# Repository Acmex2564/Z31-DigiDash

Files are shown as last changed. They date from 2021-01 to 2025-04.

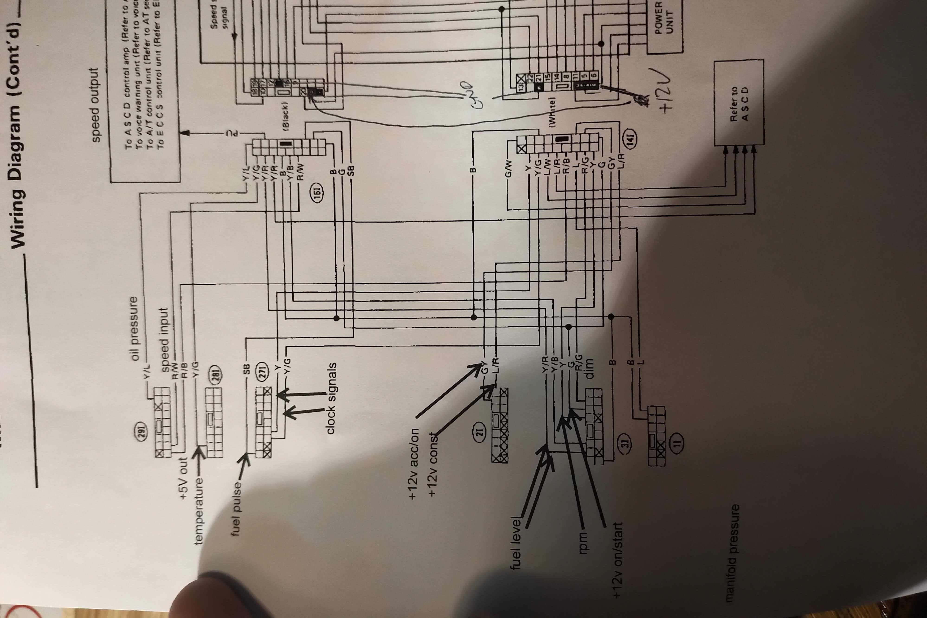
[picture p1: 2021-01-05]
Images/ex_IMG_20210104_2119277.jpg

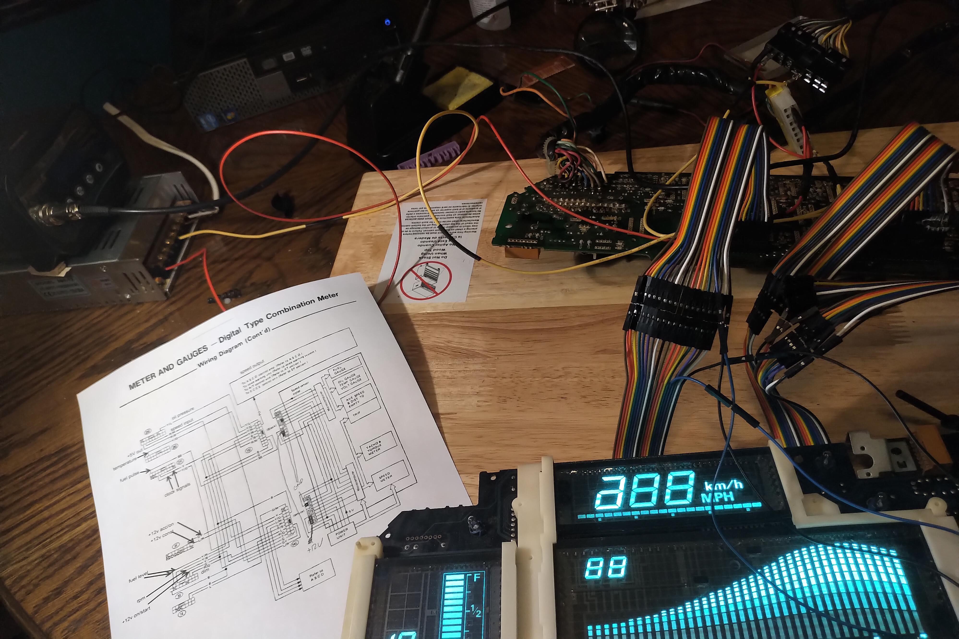
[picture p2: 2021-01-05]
Images/ex_IMG_20210104_2118492.jpg

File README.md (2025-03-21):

# Z31-DigiDash
Reverse Engineering of the 300zx (Z31) Digital Cluster &amp; Design of replacement PCBs

Z31 digital clusters are one of, if not the best examples of this pure 1980s trend. Comprehensive instrumentation, large graphics, and gorgeous VFD illumination were a somewhat expensive option on the 300zx, as well as on Maxima, 240SX, Corvette, Celica/Supra, and a variety of other cars. As the cars languished in the transition period between "late model" and "classic", though, the digital package for the 300zx was not well liked.

It had 3 major issues:

* Terrible update speed
* Lack of brightness
* Unreliability

Now, as Z31s sit at the bottom of the depreciation curve, more people see them as '80s Grand Touring icons and not just as transporation or "sports cars", and a functioning digital dash can be a highlight instead of a detractor.

I have the personal goal of solving at least two of the 3 main problems with these units, by reverse engineering them in the existing state, and designing a drop-on processor board and replacement power supply module. 

See files "Physical Description.md", "Logical Description.md", and "Electrical Description.md" for my observations so far. Also present are images showing how to power up the dash out of the car, and a picture of a printout that I used to map out the input pins.

Note: I am a hobbiest. I am not a EE, CS, Developer, or any related field. Generally, I do my best to read and cargo-cult my way into a working solution. Progress will be slow. The modular design has made it easy to get quick progress and seize control of the actual display, so input, input protection, and power supply will be the main challenges.

Note: None of the boards as-presented are in a state fit to be used without major effort. Big chunks of the Compute-Early-1 design were never tested before I moved on to Compute-Early-2 after component obselecence, etc. and the code to do more than flash the display on the bench was never developed.

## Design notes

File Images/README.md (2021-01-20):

# Powerup & Analysis Images

These images show the contacts on the stock connectors used to power up the cluster out of the car. Forgive the mess and the nano living off to the side, I had to set the project aside for a few months right after working out how to seize control of the VFD shift registers and light arbitrary segments of the displays. Having just returned to it, this is the same configuration it was in after completing that step. 

# FOR THE LOVE OF GOD, DON'T USE MY WIRE COLORS
I suspect I may have been slightly inebriated when creating this test harness, but it does work.

YELLOW IS GROUND (A total of 3, don't skimp!)
RED IS +12V (A total of 4, through two are common on the PCB anyway)

THIS WAS DUMB. DON'T DO IT. If you have connector housings for the male pins available, use those instead of bare pins. Don't just stuff bare wire in the sockets; it's mechanically and electrically poor. At least use alligator clips; it sucks but works slightly better. 

Also here are screencaps of the filament drive waveforms. Sadly, the trip meter driver has been intermittent since I got the cluster, and it was not alive while I was capturing these images.

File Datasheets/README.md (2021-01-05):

# Datasheets 

These all remain property of NEC, Hitachi, or whomever owns them now. I downloaded them off the internet, I doubt they care much anymore. 

NEC uPD6300C is the interesting one -- 20-bit serial shift-register and FIP driver.

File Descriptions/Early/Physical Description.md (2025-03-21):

# Physical Description (Early Clusters, 1984-1896)
The cluster is designed in a highly modular fashion which will dramatically ease the process. Most of the Vacuum Fluorescent Displays (VFDs) are located on a single PCB, along with their driver ICs. The trip meter display and driver is located on an additional sub-module. The mechanical odometer is an additional sub-module. The processor board is similar in footprint to the main display board, and is connected to the display board by two, twenty-by-one JAE terminal strips, and is mechanically fastened by 4 fasteners in the middle of the boards and several more along the perimeter. The processor board connects to the car by two Sumitomo 58S-series wire-to-wire connectors, totalling 32 contacts (31 used). The processor board also connects to a power supply module via two AMP(?) wire-to-board connectors, totalling 28 contacts (though not all are used).

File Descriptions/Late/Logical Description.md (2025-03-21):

# Logical description of a 1987 Model Year 300zx Digital Gauge Cluster

# Processor Board

# Display Board

# Power Supply Module

# Information Display

# Check display

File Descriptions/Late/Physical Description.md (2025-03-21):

# Physical Description (Late Clusters, 1987-1989)
The cluster is designed in a highly modular fashion which will dramatically ease the process of reverse engineering. Most of the Vacuum Fluorescent Displays (VFDs) are located on a single PCB, along with their driver ICs. The information display and driver is located on an additional sub-module. The mechanical odometer is an additional sub-module, as is the edge-lit "diagnostic display". The processor board is similar in footprint to the main display board, and is connected to the display board by two, twenty-by-one JAE terminal strips, and is mechanically fastened by 4 fasteners in the middle of the boards and several more along the perimeter. The processor board connects to the car by two Sumitomo 58S-series wire-to-wire connectors, totalling 32 contacts (31 used). The processor board also connects to a power supply module via one AMP(?) wire-to-board connectors, totalling 16 contacts (though not all are used).

The major differences between the Early and Late clusters are as follows:
* Late clusters use colored segments in the fuel gauge, tachometer, and temperature VFDs
* Late clusters use a "check" display for some vehicle parameters
* Late clusters use a simpler power supply in the same case, with a user-replacable fuse (instead of through-hole polyfuses or trace fuses)
* Late clusters have significantly more silkscreening, most of it in English, which will aid reverse engineering

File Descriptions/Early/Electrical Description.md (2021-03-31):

# Electrical Description of a 1984 Model 300zx Digital Gauge Cluster

# Main Harness Connectors
There are 3 connectors, Sumitomo 58S-type, colored/keyed white/black/blue. Blue is the warning light pcb, and not of concern. White/black are the cluster connectors.
These are 16 position connectors, with 31 of 32 positions occupied. The numbering scheme is eccentric. 

|Pin # | Description | Connector
|---:| --- | :---
| 1.| +12V Constant | White
| 2. (&2')| GND | Black (White)
| 3. (&3')| +12V On/Start | White (Black)
| 4.| +12V Acc/On | White
| 5.| Illumination (Dim) | White
| 6.| Coil Negative (Tach) | White
| 7.| Illumination 2 | White
| 8.| +5V Out | White
| 9.| Speed Sensor In | Black
|10.| Speed Sensor Out | Black
|12.| ASCD On| Black
|13.| ASCD Cruise| White
|14.| ASCD Set Disp 1| White
|15.| ASCD Set Disp 2| White
|16.| Fuel Level (Main) | Black
|17.| Fuel Level (Sub) | Black
|18.| Oil Pressure | Black
|19.| Water Temperature | Black
|20.| Fuel Injection Pulse | Black
|21.| Time Clock 1| White
|22.| Time Clock 2| White
|23.| N/C | White
|24.| O2 Sensor ("30K MI SW") |White
|25 | Charge Warning | Black
|26.| Fuel Warning | Black
|27.| Oil Pressure Warning | Black
|28.| Security Lamp Low Side Switch | Black
|29.| +12V Security | Black
|30.| Ground (AGND?) |Black

# Signal Acquisition
There are four analog (resistance) signals acquired directly by the processor board:
* Fuel Level (Main)
* Fuel Level (Sub)
* Water Temperature
* Oil Pressure

Each of these is configured as a voltage divider with a 5V supply, a resistance between the supply and the ADC, "R(1)", and the resistive sensor between the ADC and ground "R(2)".

On the processor board, the values for R1 are given below:

|Pin #|Wire Color|Description|Designator|Value
|---:|---|---|:---|:---
|16. |Y/B|Fuel Level (Main)|R80|82Ω
|17. |Y/R|Fuel Level (Sub)|R81|100Ω
|18. |Y/L|Oil Pressure|R79|43Ω 2% (G)
|19. |Y/G|Water Temp|R78|43Ω 2G (G)

These produce the following ADC voltages, based on the values specified in the service manual, for the digital tank gauge sending unit:
|Pin #|Description|Range (Ω)|Range (V)
|---: |---|:---|:---
|16.  |Fuel Level (Main)|10Ω(@F) <-> 520Ω(@E)|0.54V(@F) <-> 4.3V(@E)
|17.  |Fuel Leve (Sub)  |0Ω <-> 930Ω|0.2V(@0.25) <-> 4.5V(@E)
|18.  |Oil Pressure |
|19.  |Water Temp |

Although the precise nature of the signal acquisition cannot be determined due to the presence of ceramic "hybrid" integrated circuits, these values are reasonable for the 5V ADCs present on the board. 
Sufficient headroom remains that values out of range will allow the MCU to detect short/open circuit conditions, and disregard any such readings.

# Display Board
|Pin # | Description | AC Volts | AC Freq. | DC Volts (Offset)
|-----:|--- |:--- |:--- |:---
|3. | ? | 0 | N/A | +5V
|9. | ? | 0 | N/A | +5V
|13. | Volt/Pres/Temp Filament A | 2.6V | 103kHz | -18.5V
|14. | Volt/Pres/Temp Filament B | 2.6V | 103kHz | -18.5V
|15. | Tachometer Filament A | 3.2V | 103kHz | -18.5V
|16. | Tachometer Filament B | 3.2V | 103kHz | -18.5V
|17. | Speedometer Filament A | 3.4V | 103kHz | -18.5V
|18. | Speedometer Filament B | 3.4V | 103kHz | -18.5V
|19. | Fuel Filament A | 2.3V | 152kHz | -18.5V
|20. | Fuel Filament B | 2.3V | 152kHz | -18.5V
|21. | Vss (GND) | 0 | N/A | 0V
|22. | Vss (GND) | 0 | N/A | 0V
|23. | Grid/Anode Bias | 0 | N/A | -22.5
|24. | N/C | N/A | N/A | N/A
|25. | Vcc (Logic Supply) | 0 | N/A | +5V
|26. | Vcc (Logic Supply) | 0 | N/A | +5V
|27. | N/C | N/A | N/A | N/A
|28. | N/C | N/A | N/A | N/A
|37. | Tachometer Filament Dupe
|38. | Tachometer Filament Dupe
|39. | Trip Computer Filament Dupe
|40. | Trip Computer Filament Dupe

# Trip Meter Module
|Pin # | Description | AC Volts | AC Freq. | DC Volts (Offset)
|-----:|--- |:--- |:--- |:---
|5. | Trip Computer Filament A | | | -18.5V
|6. | Trip Computer Filament B | | | -18.5V
|19. | Vcc (Logic Supply)  | ? | ??? | +5V
|21. | Grid/Anode Bias | 0 | N/A | -22.5
|22. | Vss (GND) | 0 | N/A | 0V

Resistance values for the filaments are necessary to determine the nominal drive current. They measure at:

|Pin # | Description | Pair Resistance | Anticipated Current
|-----:|--- |:--- |:---
|13. | Volt/Pres/Temp Filament A | 2.8Ω | 930mA 
|14. | Volt/Pres/Temp Filament B | 2.6Ω | 930mA 
|15. | Tachometer Filament A | 2.0Ω | 1600mA 
|16. | Tachometer Filament B | 2.0Ω | 1600mA 
|17. | Speedometer Filament A | 6.1Ω | 560mA 
|18. | Speedometer Filament B | 6.1Ω | 560mA 
|19. | Fuel Filament A | 2.6Ω | 880mA 
|20. | Fuel Filament B | 2.6Ω | 880mA 

However, this is incorrect. Despite reading about the PTC nature of the filaments, I didn't actually comprehend this. 
I measured approximately 40mA AC filament current at 2.4V RMS for the Volt/Pres/Temp VFD panel, in addition to 7mA of DC grid/anode current with all segments illuminated. 

|Pin # | Description | Pair Resistance | Anticipated Current
|-----:|--- |:--- |:---
|5. | Trip Computer Filament A | | 
|6. | Trip Computer Filament B | | 

These currents are very high, which explains the high operating temperature of the stock power supply box.

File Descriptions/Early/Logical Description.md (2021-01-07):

# Logical description of a 1984 Model Year 300zx Digital Gauge Cluster

In keeping with the modular physical construction of the gauge cluster, the signal architecture is also laid out in a sensible manner.

# Processor Board

Due to the limited processing capability of 1970s microcontrollers, the cluster is organized around:

* Two Hitachi HD6301VP microcontrollers (MCUs)
* A Hitachi HD46821P (AKA HD6821P) Peripheral Interface Adapter (PIA)
* A Hitachi HM6117LPJ-3 CMOS Static RAM (SRAM).
* Toshiba TC5090AP Phentaphasic Integration Analog-to-Digital Converter(s)

* Other assorted Transistor-Transistor Logic (TTL) chips

As laid out in the FSM, the cluster can be thought of as basically two separate computers:

* One responsible for the Fuel, Temperature, Voltage, and Oil Pressure
* One responsible for speed, tachometer, and manifold pressure. 

Some additional discrete components are responsible for deriving the negative voltages that are sent to the power supply module.

# Display Board

The only significant ICs on this board are 11  NEC uPD6300C 20-bit combination shift-register and Fluorescent Indicator Panel (FIP) drivers. 
These take a serial stream from a microprocessor, shifting the input from serial to parallel outputs to the anodes and grids of the actual VFD modules. 

These are split into two serial banks, one for each processor. All the chips in a bank share the Serial Clock (SCK), Serial In (SI), and Latch (LH) inputs. 
Nearly each of these drivers operates in a standalone mode, with it's own Chip Select (CS) pin to the appropriate MCU. 
The exception are the two drivers for the Tachometer; the Serial Out of the first driver is connected to the Serial In of the second. 
All drivers share the Blanking Input (BI) pin, which is the global display enable/disable. 

From this point forward, I will refer to these as the "Main" drivers, for the speed and tachometer displays, and the "Satellite" drivers for the other displays. Due to the lack of convenient reference designators for these ICs, I will use the designator for the closest Resistor Array (RA) to identify them. 

All pins for these drivers are brought out to the two connectors between the processor and display board, lableled "CONN 1" and "CONN 2", with a continuous numbering from 1-40 on the board. Power signals are omitted here.

|Pin # | Description | Gauge Panel
|-----:|--- |:---
|1. | ~BI | All
|2. | ~SCK (Satellite) | Fuel, Temp, Volts, Oil Pressure
|4. | ~CS (Driver RA14)  | Fuel (Quantity)
|5. | ~CS (Driver RA16)  | Oil
|6. | ~CS (Driver RA17)  | Water Temperature
|7. | ~CS (Driver RA19)  | Volts
|8. | ~CS (Driver RA15)  | Fuel (Level)
|10. | LH (Satellite) | Fuel, Temp, Volts, Oil Pressure
|11. | SI (Satellite) | Fuel, Temp, Volts, Oil Pressure
|29. | SI (Main)
|30. | LH (Main)
|31. | ~CS (Driver RA7)
|32. | ~CS (Driver RA12)
|33. | ~CS (Driver RA10)
|34. | ~CS (Driver RA4)
|35. | ~CS (Driver RA5)
|36. | ~SCK (Main)

# Power Supply Module

The power supply module produces the pulsed DC filament drive required to evenly light VFDs. It also produces 5VDC for the engine bay sensors, though NOT the 5VDC for the processor(s) or SRAM retention. 
There are no large ICs on this board; only power transistors, diodes, coupling transformers, and passive components. 
As I do not intend to reuse this module, I have focused effort here on understanding it's inputs and outputs. 
This will be (or has been) documented in the "Electrical Description"

# Trip Meter Module

Same story here -- two Mitsubishi M54844P 8-Digit, 8-Segment FIP Drivers. These read in parallel hex data convert it to 8 digits of 7 segment output. 
Two connectors, no visible numbering though. They did provide reference designators for the chips though, which is nice. 

CONN 1
|Pin # | Description
|-----:|---
|1. | S0 (IC31)
|2. | S1 (IC31)
|3. | S2 (IC31)
|4. | S3 (IC31)
|7. | S0 (IC30)
|8. | S1 (IC30)
|9. | S2 (IC30)
|10. | S3 (IC30)

CONN 2
|Pin # | Description
|-----:|---
|11. | RESET (IC30)
|12. | ~WR (IC30)
|15. | ~WR (IC31)
|16. | CTL (IC31)
|18. | RESET (IC31)
|20. | MODE (IC30)

I think these may be tied in with a 3-to-8 line converter and a timebase generator on the processor board, but have not yet sounded this out. The reasoning is that the clock (A 555 timer) is on the module, with no possible sync to the MCU. The external clock is required because the M54844P does output multiplexing, but how are the inputs synchronized? It only has to do 8 inputs, because the drivers are placed reset to change the displayed output, but surely some form of sync is needed?

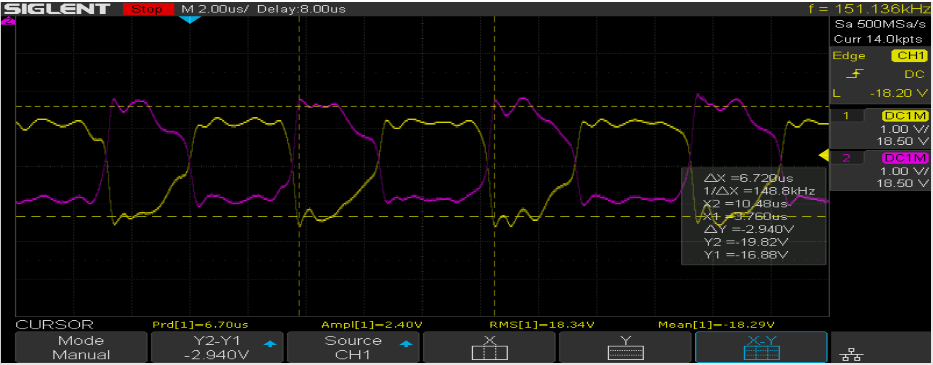
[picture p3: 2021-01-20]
Images/Waveform_FD_Fuel_2.PNG

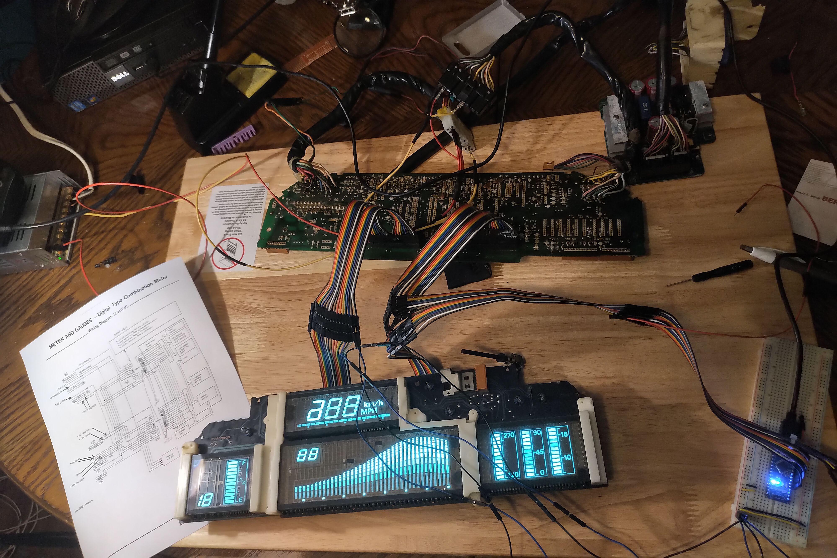
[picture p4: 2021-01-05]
Images/ex_IMG_20210104_2118250.jpg

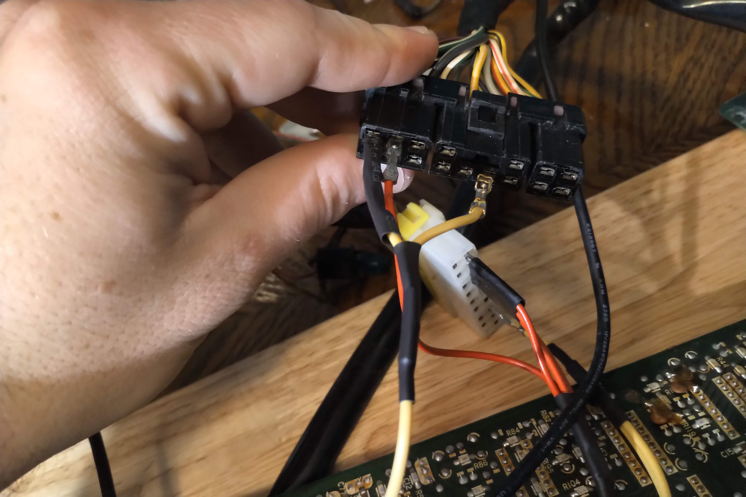
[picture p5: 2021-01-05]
Images/ex_IMG_20210104_2118332.jpg

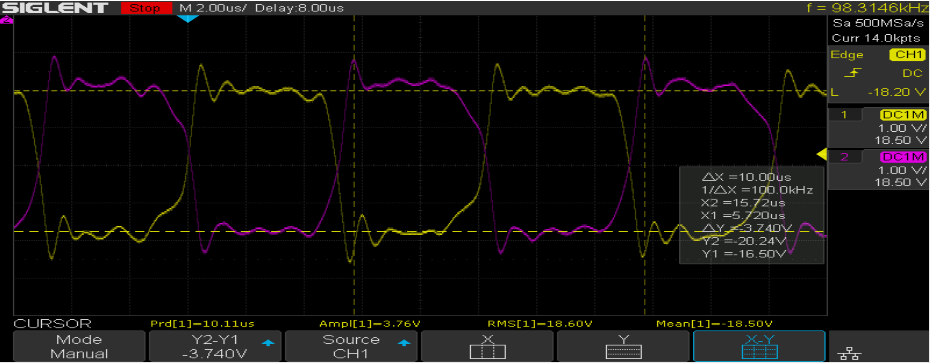
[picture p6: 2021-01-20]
Images/Waveform_FD_Speed.PNG

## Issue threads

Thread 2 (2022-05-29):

Put 5V regulator on cluster compute module

Acmex2564, 2022-05-29:
Debugging is inconvenient when 5V is generated off-board. Put the linear regulator replacement somewhere on the compute module

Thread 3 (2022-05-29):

Correct board connector location

Acmex2564, 2022-05-29:
Current connector locations are not conducive to getting the cables out of the cluster housing. Relocate them to approximate existing connector locations.

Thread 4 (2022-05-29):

Correct cluster housing back stays

Acmex2564, 2022-05-29:
Stock cluster compute modules use a pair of standoffs to the back of the cluster housing. These should be retained.

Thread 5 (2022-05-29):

Incorrect voltage dividers on analog voltage inputs to MCP3008.

Acmex2564, 2022-05-29:
Voltage dividers are reversed.

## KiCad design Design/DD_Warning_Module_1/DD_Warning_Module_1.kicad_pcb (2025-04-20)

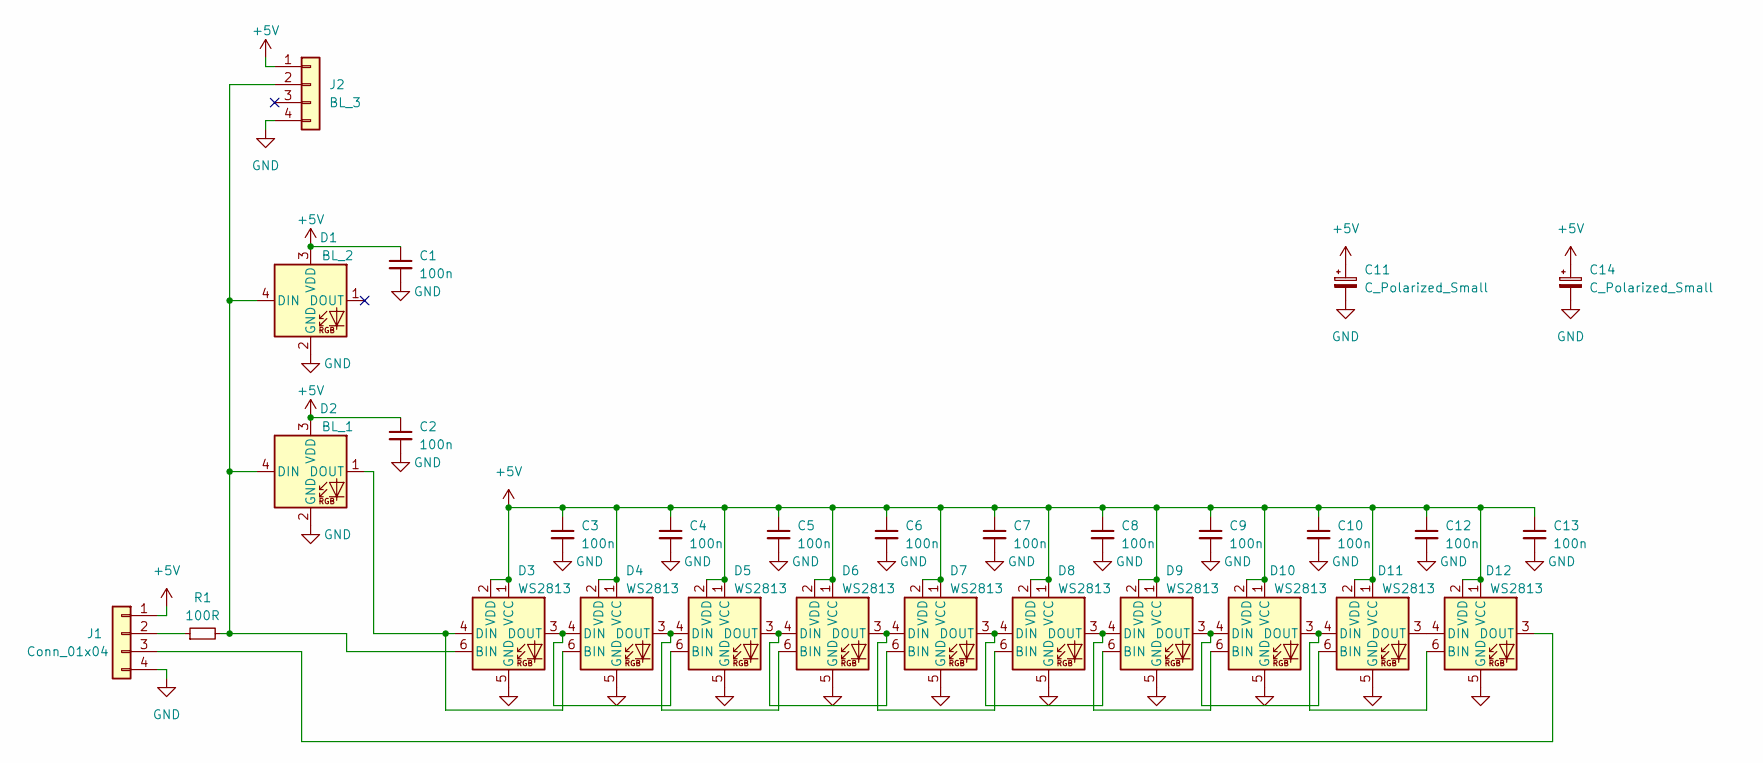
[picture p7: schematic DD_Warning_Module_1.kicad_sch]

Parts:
C1, C2, C3, C4, C5, C6, C7, C8, C9, C10, C12, C13: 100n; C_0805_2012Metric_Pad1.18x1.45mm_HandSolder
C11, C14: C_Polarized_Small; CP_Radial_D8.0mm_P2.50mm
D1: BL_2; LED_D5.0mm-4_RGB
D2: BL_1; LED_D5.0mm-4_RGB
D3, D4, D5, D6, D7, D8, D9, D10, D11, D12: WS2813; LED_WS2812_PLCC6_5.0x5.0mm_P1.6mm
J1: Conn_01x04; JST_XH_B4B-XH-A_1x04_P2.50mm_Vertical
J2: BL_3; JST_XH_B4B-XH-A_1x04_P2.50mm_Vertical
R1: 100R; R_0805_2012Metric_Pad1.20x1.40mm_HandSolder

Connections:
+5V: C1.1, C2.1, C3.1, C4.1, C5.1, C6.1, C7.1, C8.1, C9.1, C10.1, C11.1, C12.1, C13.1, C14.1, D1.3 (VDD), D2.3 (VDD), D3.1 (VCC), D3.2 (VDD), D4.1 (VCC), D4.2 (VDD), D5.1 (VCC), D5.2 (VDD), D6.1 (VCC), D6.2 (VDD), D7.1 (VCC), D7.2 (VDD), D8.1 (VCC), D8.2 (VDD), D9.1 (VCC), D9.2 (VDD), D10.1 (VCC), D10.2 (VDD), D11.1 (VCC), D11.2 (VDD), D12.1 (VCC), D12.2 (VDD), J1.1, J2.1
GND: C1.2, C2.2, C3.2, C4.2, C5.2, C6.2, C7.2, C8.2, C9.2, C10.2, C11.2, C12.2, C13.2, C14.2, D1.2 (GND), D2.2 (GND), D3.5 (GND), D4.5 (GND), D5.5 (GND), D6.5 (GND), D7.5 (GND), D8.5 (GND), D9.5 (GND), D10.5 (GND), D11.5 (GND), D12.5 (GND), J1.4, J2.4
unnamed: D1.4 (DIN), D2.4 (DIN), D3.6 (BIN), J2.2, R1.2
unnamed: D2.1 (DOUT), D3.4 (DIN), D4.6 (BIN)
unnamed: D3.3 (DOUT), D4.4 (DIN), D5.6 (BIN)
unnamed: D4.3 (DOUT), D5.4 (DIN), D6.6 (BIN)
unnamed: D5.3 (DOUT), D6.4 (DIN), D7.6 (BIN)
unnamed: D6.3 (DOUT), D7.4 (DIN), D8.6 (BIN)
unnamed: D7.3 (DOUT), D8.4 (DIN), D9.6 (BIN)
unnamed: D8.3 (DOUT), D9.4 (DIN), D10.6 (BIN)
unnamed: D9.3 (DOUT), D10.4 (DIN), D11.6 (BIN)
unnamed: D10.3 (DOUT), D11.4 (DIN), D12.6 (BIN)
unnamed: D11.3 (DOUT), D12.4 (DIN)
unnamed: D12.3 (DOUT), J1.3
unnamed: J1.2, R1.1

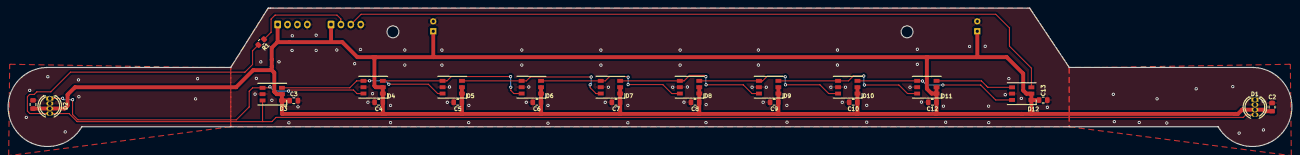
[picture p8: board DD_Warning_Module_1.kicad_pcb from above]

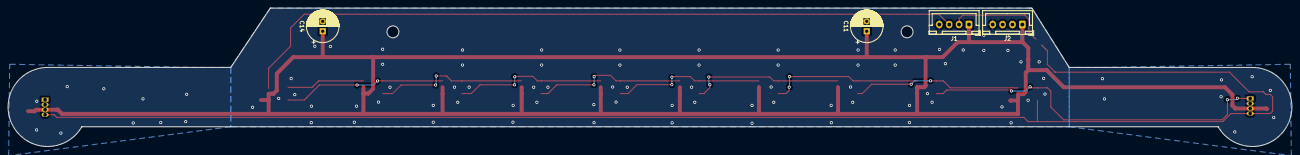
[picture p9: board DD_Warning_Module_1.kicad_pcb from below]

Board: 2 copper layers, 324.6 x 35.0 mm, 29 parts (4 on the bottom side), 15 nets.

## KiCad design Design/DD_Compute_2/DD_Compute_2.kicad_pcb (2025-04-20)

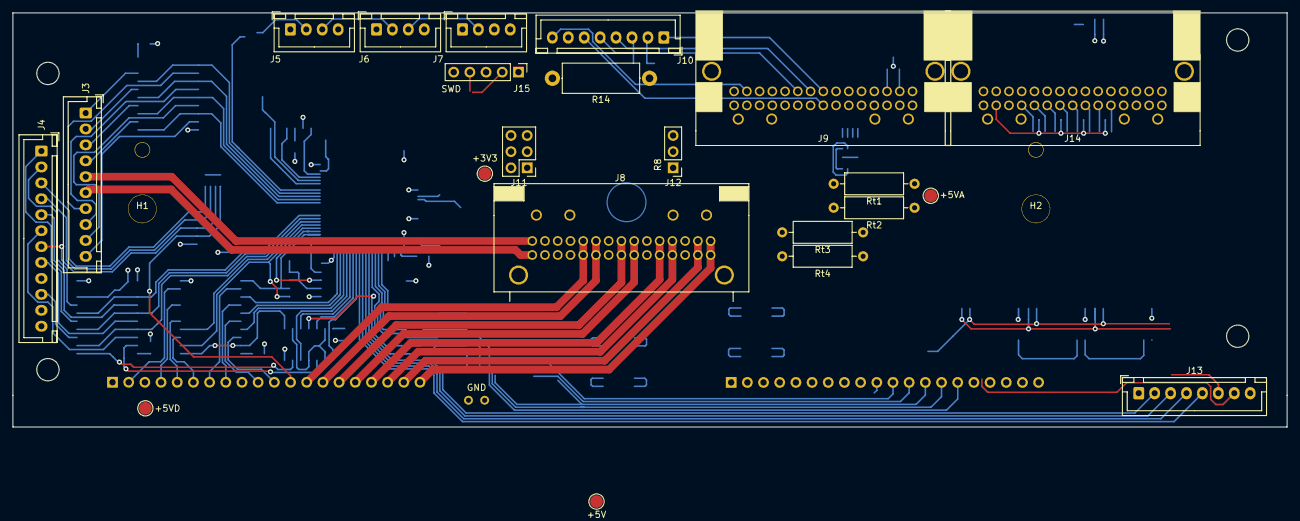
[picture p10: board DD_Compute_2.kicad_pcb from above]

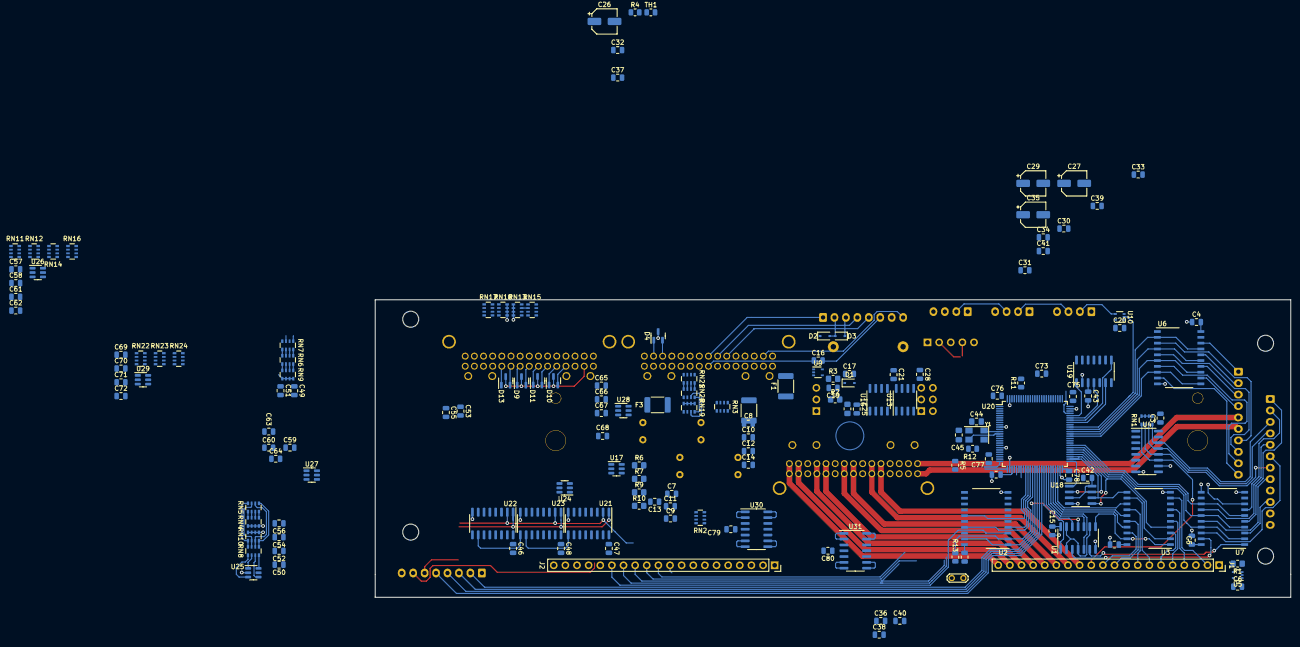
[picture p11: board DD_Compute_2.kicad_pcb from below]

Board: 4 copper layers, 200.0 x 65.0 mm, 183 parts (155 on the bottom side), 224 nets.

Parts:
3.3V1: +3V3; TestPoint_Pad_D2.0mm
5V_Analog1: +5VA; TestPoint_Pad_D2.0mm
5V_Disp1: +5VD; TestPoint_Pad_D2.0mm
5V_Logic1: +5V; TestPoint_Pad_D2.0mm
C1, C2, C3, C4, C5, C6, C7, C8, C9, C10, C11, C12, C14, C15, C16, C20, C21, C28, C31, C38, C39, C42, C43, C46, C47, C48, C49, C50, C51, C52, C53, C54, C55, C56, C57, C58, C59, C60, C61, C62, C63, C64, C65, C66, C67, C68, C69, C70, C71, C72, C73, C74, C75, C76, C77, C78, C79, C80: 100nF; C_0805_2012Metric
C13, C17, C19, C25: 10n; C_0805_2012Metric
C26, C27, C29, C35: 47uF; CP_Elec_5x5.3
C30, C32, C34, C36, C37: 1uF; C_0805_2012Metric
C33, C40, C41: 10nF; C_0805_2012Metric
C44, C45: 20pF; C_0805_2012Metric_Pad1.18x1.45mm_HandSolder
D1, D2, D3: 1N4148WS; D_SOD-323
D4: NUP2105L; SOT-23
D9, D10, D11, D13: BAV70; SOT-23
F1, F2, F3: Polyfuse_Small; Fuse_1812_4532Metric_Pad1.30x3.40mm_HandSolder
GND1: GND; TestPoint_2Pads_Pitch2.54mm_Drill0.8mm
H1, H2: Peg; Z31_DD_Mountpeg
H3, H4, H5, H6: Hole; MountingHole_3.5mm
J1: DISP. BOARD CONN 1 (1-20); PinSocket_1x20_P2.54mm_Vertical
J2: DISP. BOARD CONN 2 (21-40); PinSocket_1x20_P2.54mm_Vertical
J3: TRIP BOARD CONN 1 (1-10); JST_XH_B10B-XH-A_1x10_P2.50mm_Vertical
J4: TRIP BOARD CONN 2 (11-22); JST_XH_B12B-XH-A_1x12_P2.50mm_Vertical
J5, J6, J7: Conn_01x03; JST_XH_B4B-XH-A_1x04_P2.50mm_Vertical
J8: POWER SUPPLY - 0349580340; 34958
J9: CAR INTERFACE - 0349610341 - SIG; 349610340
J10: DISP_BOARD_CONN_3; JST_XH_B8B-XH-A_1x08_P2.50mm_Vertical
J11: ISOLATED OUPTUTS & POWER; PinHeader_2x03_P2.54mm_Vertical
J12: ISOLATED INPUTS; PinHeader_1x03_P2.54mm_Vertical
J13: ODOMETER MODULE; JST_XH_B8B-XH-A_1x08_P2.50mm_Vertical
J14: CAR INTERFACE - 0349610341; 349610340
J15: SWD; PinHeader_1x05_P2.54mm_Vertical
R1: 47k; R_0805_2012Metric_Pad1.20x1.40mm_HandSolder
R2: 2.2k; R_0805_2012Metric_Pad1.20x1.40mm_HandSolder
R3, R8: 1k; R_0805_2012Metric_Pad1.20x1.40mm_HandSolder
R4, R5: 47k; R_0805_2012Metric
R6, R9: 75k 1%; R_0805_2012Metric_Pad1.20x1.40mm_HandSolder
R7, R10: 35.7k 1%; R_0805_2012Metric_Pad1.20x1.40mm_HandSolder
R11, R12, R13: 100k; R_0805_2012Metric
R14: 47; R_Axial_DIN0414_L11.9mm_D4.5mm_P15.24mm_Horizontal
RN1, RN2, RN3, RN4, RN5, RN6, RN7, RN8, RN9, RN10, RN11, RN12, RN13, RN14, RN15, RN16, RN17, RN18, RN19, RN20, RN21, RN22, RN23, RN24: 4.7k; R_Array_Convex_4x0603
Rt1, Rt2, Rt3, Rt4: R; R_Axial_DIN0309_L9.0mm_D3.2mm_P12.70mm_Horizontal
TH1: NTCG204AH473JT1; R_0805_2012Metric
U1: 74HCT00D,653; SO-14_3.9x8.65mm_P1.27mm
U2, U3, U6, U7: 74HCT244D,653; SO-20_12.8x7.5mm_P1.27mm
U4, U21, U22, U23: 74HC165D-Q100,118; SOIC-16_3.9x9.9mm_P1.27mm
U5, U9, U10: SN74LV1T34DCK; SOT-353_SC-70-5
U13, U16: VO0631T; SOIC-8_3.9x4.9mm_P1.27mm
U17, U24, U25, U26, U27, U28, U29: SRV05-4; SOT-23-6
U18: 25LC020AT-E/SN; SOIC-8_3.9x4.9mm_P1.27mm
U19: TJR1443; SO-14_3.9x8.65mm_P1.27mm
U20: STM32F103V8Tx; LQFP-100_14x14mm_P0.5mm
U30, U31: LMV324AIDR; SOIC-14_3.9x8.7mm_P1.27mm
Y1: 8MHz; Crystal_SMD_5032-4Pin_5.0x3.2mm

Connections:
12V_Sense: R9.2, R10.1, RN2.2 (R2.1), U17.4 (IO3)
+3V3: 3.3V1.1, C3.1, C21.2, C28.2, C42.2, C46.1, C47.1, C48.1, C73.1, C74.1, C75.1, C76.1, C77.1, C78.1, C79.1, C80.1, J11.2, J15.1, R1.2, R4.1, R12.1, RN1.5 (R4.2), RN1.6 (R3.2), RN1.7 (R2.2), RN1.8 (R1.2), U4.16 (VCC), U13.8 (VCC), U16.8 (VCC), U18.3 (~WP), U18.7 (~HOLD), U18.8 (VCC), U19.5 (Vio), U20.6 (VBAT), U20.11 (VDD), U20.22 (VDDA), U20.28 (VDD), U20.50 (VDD), U20.75 (VDD), U20.100 (VDD), U21.16 (VCC), U22.16 (VCC), U23.16 (VCC), U30.4 (V+), U31.4 (V+)
+5V: 5V_Logic1.1, C1.2, C2.2, C4.2, C5.1, C15.2, C26.1, C29.1, C32.1, C34.1, C43.1, U1.14 (VCC), U2.20 (VCC), U3.20 (VCC), U6.20 (VCC), U7.20 (VCC), U17.5 (VP), U19.3 (Vcc), U24.5 (VP), U25.5 (VP), U26.5 (VP), U27.5 (VP), U28.5 (VP), U29.5 (VP)
+5VA: 5V_Analog1.1, C16.1, C27.1, C30.1, C31.1, C33.1, J9.8, J9.23, J11.3, R3.2, R5.1, R8.2, RN24.3 (R3.1), RN24.4 (R4.1), Rt1.1, Rt2.1, Rt3.1, Rt4.1, U9.5 (VCC)
+5VD: 5V_Disp1.1, C6.1, C20.1, C35.1, C37.1, C39.1, C41.1, J1.3, J2.5, J2.6, J4.9, J5.1, J6.1, J7.1, J8.2, J13.1, U1.2, U1.4, U1.9, U1.13, U5.5 (VCC), U10.5 (VCC)
+12V_ACC_ON: F1.2, J9.4
+12V_CONST: F3.1, J9.1, R9.1
+12V_ON_START: F2.2, J9.3
+12V_ON_START_B: J9.33, J10.8, R14.1
+12V_Security: J9.29, J10.5, RN24.1 (R1.1)
/BOOT0: R11.1, U20.94 (BOOT0)
/CAN_EN: U19.6 (EN), U20.68 (PA9)
/CAN_RX: U19.4 (RXCAN), U20.70 (PA11)
/CAN_TX: U19.1 (TXCAN), U20.71 (PA12)
/DC_ODO: J13.5, U20.41 (PE10)
/Disp_CTL_IC31: J4.6, U7.18 (1Y0)
/Disp_Mode_IC30: J4.10, U7.3 (2Y0)
/Disp_Reset_IC30: J4.1, U7.5 (2Y1)
/Disp_Reset_IC31: J4.8, U7.16 (1Y1)
/Disp_S0_IC30: J3.7, U6.3 (2Y0)
/Disp_S0_IC31: J3.1, U6.18 (1Y0)
/Disp_S1_IC30: J3.8, U6.5 (2Y1)
/Disp_S1_IC31: J3.2, U6.16 (1Y1)
/Disp_S2_IC30: J3.9, U6.7 (2Y2)
/Disp_S2_IC31: J3.3, U6.14 (1Y2)
/Disp_S3_IC30: J3.10, U6.9 (2Y3)
/Disp_S3_IC31: J3.4, U6.12 (1Y3)
/Disp_~WR_IC30: J4.2, U7.7 (2Y2)
/Disp_~WR_IC31: J4.5, U7.14 (1Y2)
/Display_LH_Satellite: J1.10, U3.16 (1Y1)
/Display_SI_Satellite: J1.11, U3.18 (1Y0)
/Display_~CS_Fuel_Lvl: J1.8, U3.14 (1Y2)
/Display_~CS_Fuel_Qty: J1.4, U3.7 (2Y2)
/Display_~CS_Oil: J1.5, U3.5 (2Y1)
/Display_~CS_SpeedGraph: J2.15, U2.3 (2Y0)
/Display_~CS_SpeedNumeric: J2.14, U2.18 (1Y0)
/Display_~CS_TachGraphLoad: J2.12, U2.16 (1Y1)
/Display_~CS_TachGraphRpm: J2.13, U2.5 (2Y1)
/Display_~CS_TachNumeric: J2.11, U2.7 (2Y2)
/Display_~CS_Temp: J1.6, U3.3 (2Y0)
/Display_~CS_Volts: J1.7, U3.12 (1Y3)
/Display_~SCK_Main: J2.16, U2.12 (1Y3)
/Display_~SCK_Satellite: J1.2, U3.9 (2Y3)
/EN_ODO: J13.2, U20.38 (PE7)
/Extra_High_Input: J14.20, RN7.4 (R4.1)
/IC30_OE: U1.1, U20.42 (PE11)
/IC31_OE: U1.5, U20.45 (PE14)
/Illum_Data_Loop1: J5.3, J6.2
/Illum_Data_Loop2: J6.3, J7.2
/Illum_Data_Out: J5.2, U10.4 (Y)
/Indicator_Pilot_Common: J14.5, RN9.5 (R4.2), RN9.6 (R3.2), RN9.7 (R2.2), RN9.8 (R1.2)
/Indicator_Pilot_Left: J14.22, RN7.2 (R2.1)
/Indicator_Pilot_Main: J14.23, RN7.1 (R1.1)
/Indicator_Pilot_Right: J14.21, RN7.3 (R3.1)
/RESET_ODO: J13.4, U20.40 (PE9)
/SPI1_CS0: U2.13 (2A2), U20.33 (PC4)
/SPI1_CS1: U2.15 (2A1), U20.34 (PC5)
/SPI1_CS2/BOOT1: R13.1, U2.2 (1A0), U20.37 (PB2)
/SPI1_CS3: U2.17 (2A0), U20.36 (PB1)
/SPI1_CS4: U2.4 (1A1), U20.35 (PB0)
/SPI1_CS5: U20.29 (PA4), U21.15 (~CE), U22.15 (~CE), U23.15 (~CE)
/SPI1_LH: U21.1 (~PL), U22.1 (~PL), U23.1 (~PL)
/SPI1_MISO: U20.31 (PA6), U22.9 (Q7)
/SPI1_MOSI: J13.7, U20.32 (PA7)
/SPI1_SCK: J13.6, U2.8 (1A3), U20.30 (PA5), U21.2 (CP), U22.2 (CP), U23.2 (CP)
/SPI2_CS0: U3.13 (2A2), U20.48 (PB11)
/SPI2_CS1: U3.15 (2A1), U20.47 (PB10)
/SPI2_CS2: U3.17 (2A0), U20.46 (PE15)
/SWCLK: J15.4, U20.76 (PA14)
/SWDIO: J15.2, U20.72 (PA13)
/Secondary_Warning_Input/ASCD_CruiseB: C66.2, RN19.7 (R2.2), RN20.7 (R2.2), U22.4 (D5), U28.4 (IO3)
/Secondary_Warning_Input/ASCD_OnB: C65.2, RN19.8 (R1.2), RN20.8 (R1.2), U22.3 (D4), U28.6 (IO4)
/Secondary_Warning_Input/ASCD_Set_Disp_1B: C67.2, RN19.6 (R3.2), RN20.6 (R3.2), U22.5 (D6), U28.1 (IO1)
/Secondary_Warning_Input/ASCD_Set_Disp_2B: C68.2, RN19.5 (R4.2), RN20.5 (R4.2), U22.6 (D7), U28.3 (IO2)
/Secondary_Warning_Input/Belt: C50.2, RN8.1 (R1.1), U23.11 (D0), U25.3 (IO2)
/Secondary_Warning_Input/Brake_1: C54.2, RN8.3 (R3.1), U23.13 (D2), U25.4 (IO3)
/Secondary_Warning_Input/Brake_2: C56.2, RN8.4 (R4.1), U23.14 (D3), U25.6 (IO4)
/Secondary_Warning_Input/Coolant: C57.2, RN14.8 (R1.2), U23.3 (D4), U26.3 (IO2)
/Secondary_Warning_Input/Door: C62.2, RN14.5 (R4.2), U23.6 (D7), U26.6 (IO4)
/Secondary_Warning_Input/Extra_HighB: C55.2, RN6.5 (R4.2), RN9.4 (R4.1), U21.3 (D4), U24.3 (IO2)
/Secondary_Warning_Input/Extra_Low_1B: C59.2, RN17.1 (R1.1), U21.11 (D0), U27.3 (IO2)
/Secondary_Warning_Input/Extra_Low_2B: C60.2, RN17.2 (R2.1), U21.12 (D1), U27.1 (IO1)
/Secondary_Warning_Input/Extra_Low_3B: C63.2, RN17.3 (R3.1), U21.13 (D2), U27.4 (IO3)
/Secondary_Warning_Input/Extra_Low_4B: C64.2, RN17.4 (R4.1), U21.14 (D3), U27.6 (IO4)
/Secondary_Warning_Input/Headlamp: C58.2, RN14.7 (R2.2), U23.4 (D5), U26.1 (IO1)
/Secondary_Warning_Input/Left_Turn: C51.2, RN6.7 (R2.2), RN9.2 (R2.1), U21.6 (D7), U24.4 (IO3)
/Secondary_Warning_Input/Main_Beam: C49.2, RN6.8 (R1.2), RN9.1 (R1.1), U21.5 (D6), U24.6 (IO4)
/Secondary_Warning_Input/Right_Turn: C53.2, RN6.6 (R3.2), RN9.3 (R3.1), U21.4 (D5), U24.1 (IO1)
/Secondary_Warning_Input/Sensor: C52.2, RN8.2 (R2.1), U23.12 (D1), U25.1 (IO1)
/Secondary_Warning_Input/Taillamp: C61.2, RN14.6 (R3.2), U23.5 (D6), U26.4 (IO3)
/Secondary_Warning_Input/Warn_ChargeB: C70.2, RN23.7 (R2.2), U22.13 (D2), U29.1 (IO1)
/Secondary_Warning_Input/Warn_FuelB: C71.2, RN23.6 (R3.2), U22.12 (D1), U29.4 (IO3)
/Secondary_Warning_Input/Warn_Oil_PressB: C72.2, RN23.5 (R4.2), U22.11 (D0), U29.6 (IO4)
/Secondary_Warning_Input/Warn_SecurityB: C69.2, RN23.8 (R1.2), U22.14 (D3), U29.3 (IO2)
/Trip_Mode/CTL: U7.2 (1A0), U7.17 (2A0), U20.56 (PD9)
/Trip_Reset: U7.4 (1A1), U7.15 (2A1), U20.57 (PD10)
/Trip_S0: U6.2 (1A0), U6.17 (2A0), U20.65 (PC8)
/Trip_S1: U6.4 (1A1), U6.15 (2A1), U20.64 (PC7)
/Trip_S2: U6.6 (1A2), U6.13 (2A2), U20.63 (PC6)
/Trip_S3: U6.8 (1A3), U6.11 (2A3), U20.62 (PD15)
/Trip_~WR: U7.6 (1A2), U7.13 (2A2), U20.58 (PD11)
/Warning-12V-Supply: J14.6, RN4.1 (R1.1), RN4.2 (R2.1), RN4.3 (R3.1), RN4.4 (R4.1), RN11.1 (R1.1), RN11.2 (R2.1), RN11.3 (R3.1), RN11.4 (R4.1), RN13.1 (R1.1), RN13.2 (R2.1), RN13.3 (R3.1), RN13.4 (R4.1)
/Warning_Belt: D9.1 (A), J14.11, RN5.7 (R2.2), RN8.7 (R2.2), RN10.2 (R2.1)
/Warning_Brake: D13.2 (A), J14.10, RN5.6 (R3.2), RN8.6 (R3.2), RN10.3 (R3.1)
/Warning_Brake_2: D13.1 (A), J14.9, RN5.5 (R4.2), RN8.5 (R4.2), RN10.4 (R4.1)
/Warning_Bulb_Check: D9.3 (K), D10.3 (K), D11.3 (K), D13.3 (K), J14.18
/Warning_Coolant: D11.2 (A), J14.14, RN12.8 (R1.2), RN14.1 (R1.1), RN16.1 (R1.1)
/Warning_Door: D10.2 (A), J14.16, RN12.5 (R4.2), RN14.4 (R4.1), RN16.4 (R4.1)
/Warning_Extra_1: J14.26, RN15.8 (R1.2), RN17.8 (R1.2), RN18.1 (R1.1)
/Warning_Extra_2: J14.27, RN15.7 (R2.2), RN17.7 (R2.2), RN18.2 (R2.1)
/Warning_Extra_3: J14.28, RN15.6 (R3.2), RN17.6 (R3.2), RN18.3 (R3.1)
/Warning_Extra_4: J14.29, RN15.5 (R4.2), RN17.5 (R4.2), RN18.4 (R4.1)
/Warning_Headlamp: D11.1 (A), J14.13, RN12.7 (R2.2), RN14.2 (R2.1), RN16.2 (R2.1)
/Warning_Sensor: D9.2 (A), J14.12, RN5.8 (R1.2), RN8.8 (R1.2), RN10.1 (R1.1)
/Warning_Taillamp: D10.1 (A), J14.15, RN12.6 (R3.2), RN14.3 (R3.1), RN16.3 (R3.1)
/~CAN_ERR: U19.8 (~ERR), U20.69 (PA10)
/~CAN_STB: U19.14 (~STB_N), U20.67 (PA8)
/~CS_ODO: J13.3, U20.39 (PE8)
/~Disp_BI: J1.1, U5.4 (Y)
/~RESET: J15.5, R12.2, U20.14 (NRST)
ASCD_Cruise: J9.13, RN21.3 (R3.1)
ASCD_On: J9.12, J10.6, RN21.4 (R4.1)
ASCD_Set_Disp_1: J9.14, RN21.2 (R2.1)
ASCD_Set_Disp_2: J9.15, RN21.1 (R1.1)
Bias_Grid_Anode: C36.1, C38.1, C40.1, J2.3, J4.11, J8.14, J8.29
Blanking_Control: R1.1, U5.2 (A)
Clock_1_(Time): D4.1 (K), J9.21, U19.13 (CANH)
Clock_2_(Time): D4.2 (K), J9.22, U19.12 (CANL)
Coil_Negative_(Tach): J9.6, J12.2, R2.2
Filament_Fuel_A: J1.19, J8.18, J8.33
Filament_Fuel_B: J1.20, J8.19, J8.34
Filament_Speed_A: J1.17, J8.15, J8.30
Filament_Speed_B: J1.18, J8.16, J8.31
Filament_Sub_A: J1.13, J8.9, J8.24
Filament_Sub_B: J1.14, J8.10, J8.25
Filament_Tach_A: J1.15, J8.12, J8.27
Filament_Tach_B: J1.16, J8.13, J8.28
Filament_Trip_A: J3.5, J8.5
Filament_Trip_B: J3.6, J8.20
Fuel_Gauge_Main: J9.16, RN3.4 (R4.1), Rt1.2
Fuel_Gauge_Sub: J9.17, RN3.3 (R3.1), Rt2.2
Fuel_Injection_Pulse: C19.1, J9.20, J12.3, U13.3 (C2)
Fuel_Injection_Pulse_Protect: J11.5, U13.6 (VO2)
GND: C1.1, C2.1, C3.2, C4.1, C5.2, C6.2, C7.1, C8.1, C9.1, C10.1, C11.1, C12.1, C13.1, C14.1, C15.1, C16.2, C17.2, C20.2, C21.1, C26.2, C27.2, C28.1, C29.2, C30.2, C31.2, C32.2, C33.2, C34.2, C35.2, C36.2, C37.2, C38.2, C39.2, C40.2, C41.2, C42.1, C43.2, C44.2, C45.2, C46.2, C47.2, C48.2, C49.1, C50.1, C51.1, C52.1, C53.1, C54.1, C55.1, C56.1, C57.1, C58.1, C59.1, C60.1, C61.1, C62.1, C63.1, C64.1, C65.1, C66.1, C67.1, C68.1, C69.1, C70.1, C71.1, C72.1, C73.2, C74.2, C75.2, C76.2, C77.2, C78.2, C79.2, C80.2, D1.2 (A), D4.3 (A), GND1.1, J2.1, J2.2, J4.12, J5.4, J6.4, J7.4, J8.1, J8.8, J8.11, J8.17, J8.23, J8.26, J8.32, J9.2, J9.30, J9.32, J10.7, J11.1, J13.8, J15.3, R7.2, R10.2, R11.2, R13.2, RN10.5 (R4.2), RN10.6 (R3.2), RN10.7 (R2.2), RN10.8 (R1.2), RN16.5 (R4.2), RN16.6 (R3.2), RN16.7 (R2.2), RN16.8 (R1.2), RN18.5 (R4.2), RN18.6 (R3.2), RN18.7 (R2.2), RN18.8 (R1.2), RN19.1 (R1.1), RN19.2 (R2.1), RN19.3 (R3.1), RN19.4 (R4.1), RN22.3 (R3.1), RN22.4 (R4.1), TH1.2, U1.7 (GND), U2.10 (GND), U3.10 (GND), U4.3 (D4), U4.4 (D5), U4.5 (D6), U4.6 (D7), U4.8 (GND), U4.10 (DS), U5.3 (GND), U6.10 (GND), U7.8 (1A3), U7.10 (GND), U7.11 (2A3), U9.3 (GND), U10.3 (GND), U13.2 (C1), U13.5 (GND), U16.5 (GND), U17.2 (VN), U18.4 (GND), U19.2 (GND), U20.10 (VSS), U20.19 (VSSA), U20.27 (VSS), U20.49 (VSS), U20.74 (VSS), U20.99 (VSS), U21.8 (GND), U22.8 (GND), U23.8 (GND), U24.2 (VN), U25.2 (VN), U26.2 (VN), U27.2 (VN), U28.2 (VN), U29.2 (VN), U30.11 (V-), U31.11 (V-), Y1.2, Y1.4
INT_TEMP_SENSE: R4.2, TH1.1
Illum_Data: U10.2 (A), U20.66 (PC9)
Illum_Sense: R6.2, R7.1, RN2.3 (R3.1), U17.1 (IO1)
Illumination_2: J9.7, R6.1
Main_Enable: U1.12, U20.43 (PE12)
Manifold_Pressure: J9.11, RN2.4 (R4.1)
unnamed: C17.1, D1.1 (K), R2.1, U13.1 (A1)
unnamed: D2.2 (A), D3.2 (A), J10.2
unnamed: F1.1, J8.3
unnamed: F2.1, J8.4
unnamed: C7.2, RN2.8 (R1.2)
unnamed: C9.2, RN2.7 (R2.2)
unnamed: C11.2, RN2.6 (R3.2)
unnamed: C13.2, RN2.5 (R4.2)
unnamed: C14.2, RN3.8 (R1.2)
unnamed: C12.2, RN3.7 (R2.2)
unnamed: C10.2, RN3.6 (R3.2)
unnamed: C8.2, RN3.5 (R4.2)
unnamed: RN4.8 (R1.2), RN5.1 (R1.1)
unnamed: RN4.7 (R2.2), RN5.2 (R2.1)
unnamed: RN4.6 (R3.2), RN5.3 (R3.1)
unnamed: RN4.5 (R4.2), RN5.4 (R4.1)
unnamed: RN6.1 (R1.1), RN7.8 (R1.2)
unnamed: RN6.2 (R2.1), RN7.7 (R2.2)
unnamed: RN6.3 (R3.1), RN7.6 (R3.2)
unnamed: RN6.4 (R4.1), RN7.5 (R4.2)
unnamed: RN11.8 (R1.2), RN12.1 (R1.1)
unnamed: RN11.7 (R2.2), RN12.2 (R2.1)
unnamed: RN11.6 (R3.2), RN12.3 (R3.1)
unnamed: RN11.5 (R4.2), RN12.4 (R4.1)
unnamed: RN13.8 (R1.2), RN15.1 (R1.1)
unnamed: RN13.7 (R2.2), RN15.2 (R2.1)
unnamed: RN13.6 (R3.2), RN15.3 (R3.1)
unnamed: RN13.5 (R4.2), RN15.4 (R4.1)
unnamed: RN20.1 (R1.1), RN21.8 (R1.2)
unnamed: RN20.2 (R2.1), RN21.7 (R2.2)
unnamed: RN20.3 (R3.1), RN21.6 (R3.2)
unnamed: RN20.4 (R4.1), RN21.5 (R4.2)
unnamed: RN22.5 (R4.2), RN22.8 (R1.2), RN23.1 (R1.1)
unnamed: RN22.2 (R2.1), RN24.7 (R2.2)
unnamed: RN22.6 (R3.2), RN22.7 (R2.2), RN23.2 (R2.1)
unnamed: U1.11, U2.1 (1OE), U2.19 (2OE)
unnamed: U1.8, U3.1 (1OE), U3.19 (2OE)
unnamed: U1.6, U6.1 (1OE), U7.1 (1OE)
unnamed: U1.3, U6.19 (2OE), U7.19 (2OE)
unnamed: C19.2, R3.1, U13.4 (A2)
unnamed: C25.2, R8.1, U16.1 (A1)
unnamed: C44.1, U20.12 (RCC_OSC_IN), Y1.1
unnamed: C45.1, U20.13 (RCC_OSC_OUT), Y1.3
unnamed: U21.9 (Q7), U23.10 (DS)
unnamed: U22.10 (DS), U23.9 (Q7)
unnamed: U30.1, U30.2 (-)
unnamed: U30.6 (-), U30.7
unnamed: U30.8, U30.9 (-)
unnamed: U30.13 (-), U30.14
unnamed: U31.1, U31.2 (-)
unnamed: U31.6 (-), U31.7
unnamed: U31.8, U31.9 (-)
unnamed: U31.13 (-), U31.14
Oil_Pressure: J9.18, RN3.2 (R2.1), Rt3.2
PS_TEMP_SENSE: J8.22, R5.2, RN2.1 (R1.1)
SPI2_CS5: U18.1 (~CS), U20.51 (PB12)
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

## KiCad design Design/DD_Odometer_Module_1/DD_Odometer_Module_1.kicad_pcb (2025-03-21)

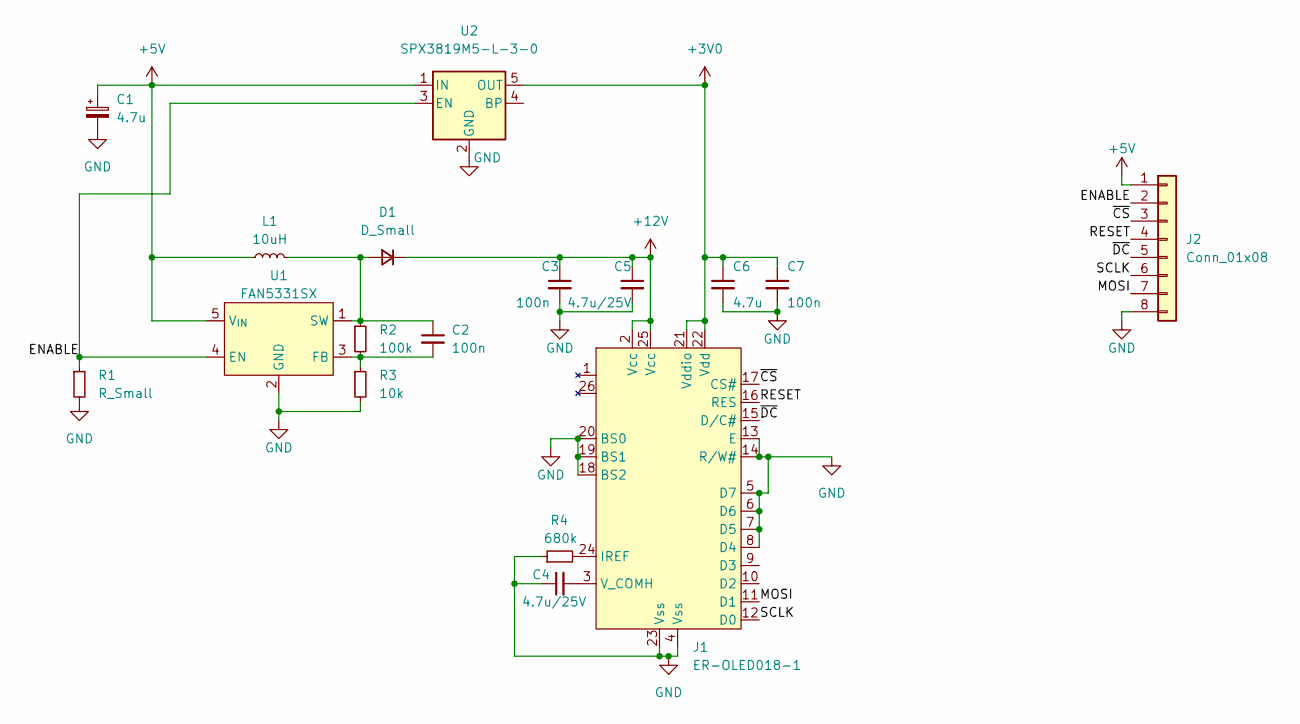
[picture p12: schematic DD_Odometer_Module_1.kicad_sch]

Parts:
C1, C6: 4.7u; C_0805_2012Metric_Pad1.18x1.45mm_HandSolder
C2, C3, C7: 100n; C_0805_2012Metric_Pad1.18x1.45mm_HandSolder
C4, C5: 4.7u/25V; C_0805_2012Metric_Pad1.18x1.45mm_HandSolder
D1: D_Small; D_SOD-123
J1: ER-OLED018-1; ER-CON26HT-1
J2: Conn_01x08; JST_XH_B8B-XH-AM_1x08_P2.50mm_Vertical
L1: 10uH; L_1008_2520Metric_Pad1.43x2.20mm_HandSolder
R1: R_Small; R_0805_2012Metric_Pad1.20x1.40mm_HandSolder
R2: 100k; R_0805_2012Metric_Pad1.20x1.40mm_HandSolder
R3: 10k; R_0805_2012Metric_Pad1.20x1.40mm_HandSolder
R4: 680k; R_0805_2012Metric_Pad1.20x1.40mm_HandSolder
U1: FAN5331SX; TSOP-5_1.65x3.05mm_P0.95mm
U2: SPX3819M5-L-3-0; SOT-23-5

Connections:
+3V0: C6.1, C7.1, J1.21 (Vddio), J1.22 (Vdd), U2.5 (OUT)
+5V: C1.1, J2.1, L1.1, U1.5 (V_{IN}), U2.1 (IN)
+12V: C3.1, C5.1, D1.1 (K), J1.2 (Vcc), J1.25 (Vcc)
/ENABLE: J2.2, R1.1, U1.4 (EN), U2.3 (EN)
/MOSI: J1.11 (D1), J2.7
/RESET: J1.16 (RES), J2.4
/SCLK: J1.12 (D0), J2.6
/~CS: J1.17 (CS#), J2.3
/~DC: J1.15 (D/C#), J2.5
GND: C1.2, C3.2, C4.1, C5.2, C6.2, C7.2, J1.4 (Vss), J1.5 (D7), J1.6 (D6), J1.7 (D5), J1.8 (D4), J1.13 (E), J1.14 (R/W#), J1.18 (BS2), J1.19 (BS1), J1.20 (BS0), J1.23 (Vss), J2.8, R1.2, R3.2, R4.1, U1.2 (GND), U2.2 (GND)
unnamed: C2.1, D1.2 (A), L1.2, R2.1, U1.1 (SW)
unnamed: C2.2, R2.2, R3.1, U1.3 (FB)
unnamed: C4.2, J1.3 (V_COMH)
unnamed: J1.24 (IREF), R4.2

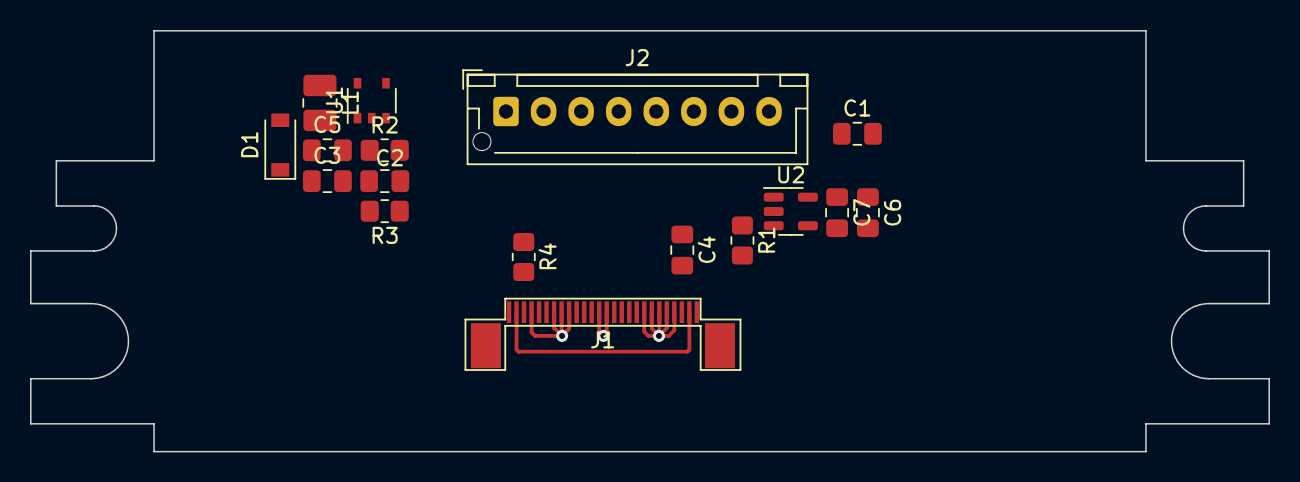
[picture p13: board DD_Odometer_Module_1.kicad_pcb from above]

Board: 2 copper layers, 82.4 x 28.0 mm, 17 parts (0 on the bottom side), 14 nets.

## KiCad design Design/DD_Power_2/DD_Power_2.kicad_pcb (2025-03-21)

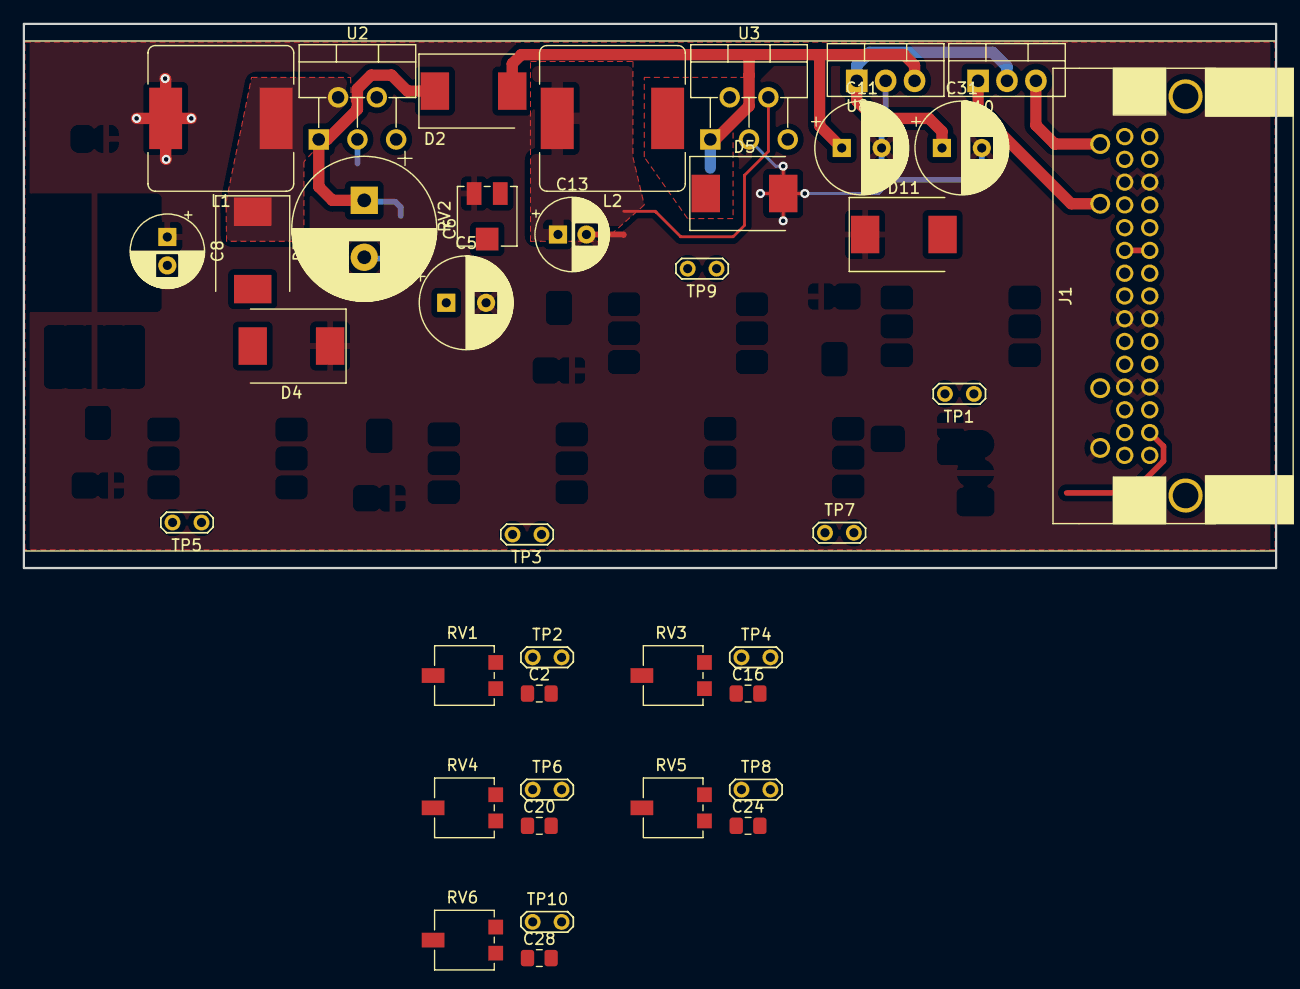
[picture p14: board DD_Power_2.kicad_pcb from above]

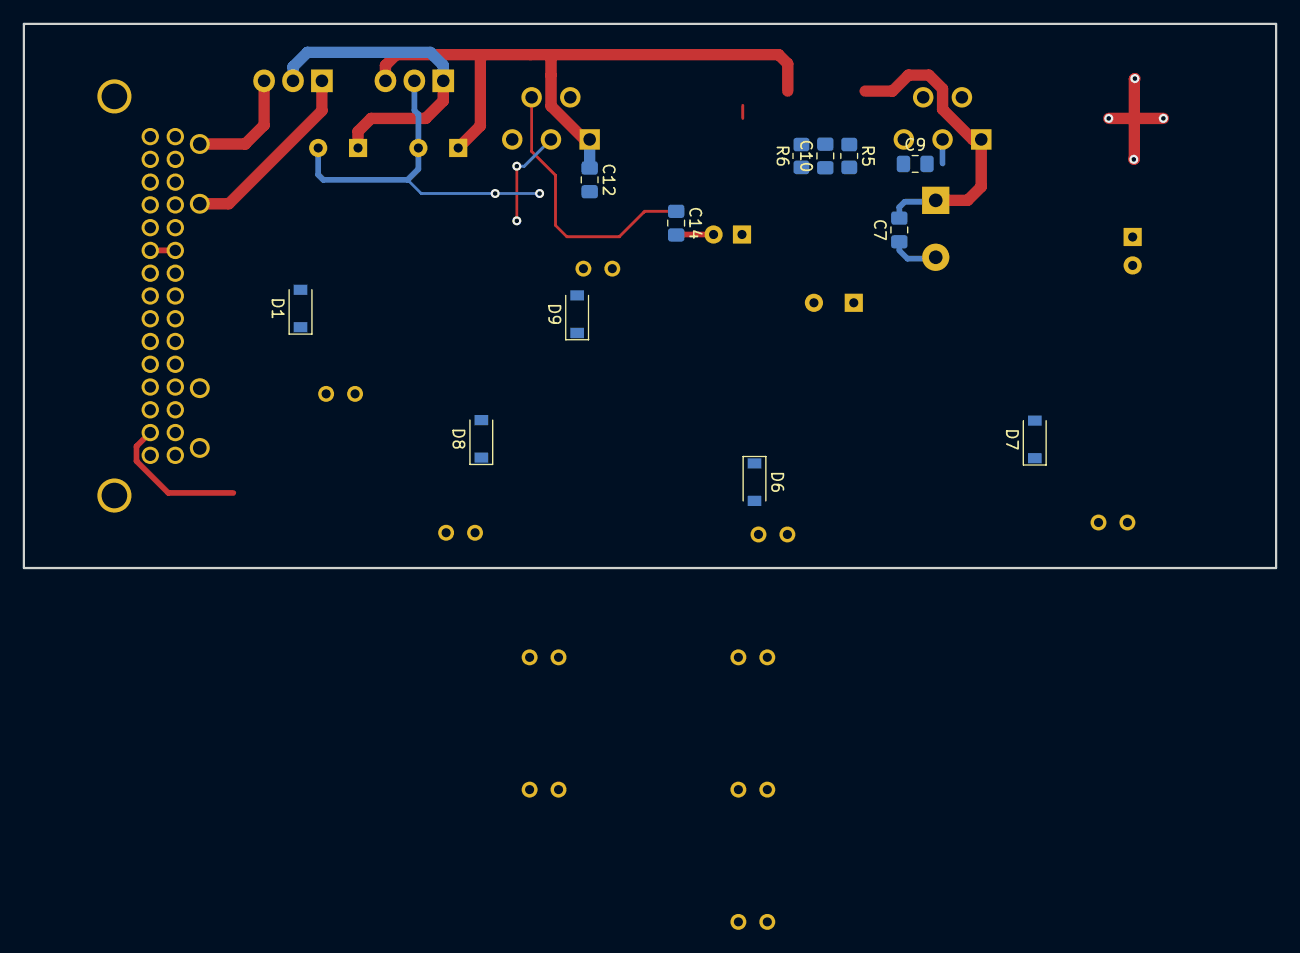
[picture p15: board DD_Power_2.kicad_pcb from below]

Board: 2 copper layers, 110.0 x 47.8 mm, 51 parts (12 on the bottom side), 27 nets.

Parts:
C2, C16, C20, C24, C28: 1uF; C_0805_2012Metric_Pad1.18x1.45mm_HandSolder
C5, C11, C31: 100uF 50V; CP_Radial_D8.0mm_P3.50mm
C6: 470uF/50V; CP_Radial_D12.5mm_P5.00mm
C7, C9, C12, C14: C_Small; C_0805_2012Metric_Pad1.18x1.45mm_HandSolder
C8, C13: 220u/25V; CP_Radial_D6.3mm_P2.50mm
C10: 180pF; C_0805_2012Metric_Pad1.18x1.45mm_HandSolder
D1, D6, D7, D8, D9: D_Zener; D_SOD-123
D2, D3, D5: B540C-13-F; D_SMC
D4: 1N5400; D_SMC
D10: MBR20100CT-G1; TO-220-3_Vertical
D11: D_TVS; D_SMC
J1: POWER SUPPLY - 0349610340; 34961
L1, L2: 33uH, 3.5A; L_Bourns_SRR1260
R5: 10k; R_0805_2012Metric_Pad1.20x1.40mm_HandSolder
R6: 1k; R_0805_2012Metric_Pad1.20x1.40mm_HandSolder
RV1, RV3, RV4, RV5, RV6: 10k; Potentiometer_Vishay_TS53YL_Vertical
RV2: 10k; Potentiometer_Vishay_TS53YJ_Vertical
TP1, TP2, TP3, TP4, TP5, TP6, TP7, TP8, TP9, TP10: TestPoint; TestPoint_2Pads_Pitch2.54mm_Drill0.8mm
U2: LM2596T-ADJ; TO-220-5_P3.4x3.7mm_StaggerOdd_Lead3.8mm_Vertical
U3: LM2596T-5; TO-220-5_P3.4x3.7mm_StaggerOdd_Lead3.8mm_Vertical
U8: L7815; TO-220-3_Vertical

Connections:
+5VD: C13.1, C14.1, J1.2, L2.2, U3.4 (FB)
/+12V_2_PROTECT: C11.1, C12.1, D2.2 (A), U3.1 (VIN), U8.3 (OUT)
/+12V_ACC_ON: D10.1 (A), J1.3
/+12V_ON_START: D10.3 (A), J1.4
/-22.5V_BIAS: C6.2, C7.2, C8.2, C9.2, D1.2 (A), D3.2 (A), D4.2 (A), D6.2 (A), D7.2 (A), D8.2 (A), D9.2 (A), J1.14, J1.29, R6.1, U2.3 (GND)
/FILAMENT_01A: J1.33, TP1.1
/FILAMENT_01B: J1.34, TP2.1
/FILAMENT_02A: J1.30, TP4.1
/FILAMENT_02B: J1.31, TP3.1
/FILAMENT_03A: J1.27, TP6.1
/FILAMENT_03B: J1.28, TP5.1
/FILAMENT_04A: J1.24, TP8.1
/FILAMENT_04B: J1.25, TP7.1
/FILAMENT_05A: J1.5, TP10.1
/FILAMENT_05B: J1.20, TP9.1
/Negative Supply/Feedback: C10.2, R5.1, R6.2, U2.4 (FB)
GND: C2.2, C5.2, C8.1, C9.1, C10.1, C11.2, C12.2, C13.2, C14.2, C16.2, C20.2, C24.2, C28.2, C31.2, D4.1 (K), D5.2 (A), D11.1 (A1), J1.1, J1.8, J1.11, J1.17, J1.23, J1.26, J1.32, L1.2, RV2.1, U3.3 (GND), U8.2 (GND)
unnamed: RV1.1, RV1.2
unnamed: C5.1, C6.1, C7.1, D2.1 (K), U2.1 (VIN)
unnamed: RV3.1, RV3.2
unnamed: RV4.1, RV4.2
unnamed: RV5.1, RV5.2
unnamed: RV6.1, RV6.2
unnamed: C31.1, D10.2 (K), D11.2 (A2), U8.1 (IN)
unnamed: D3.1 (K), L1.1, U2.2 (OUT)
unnamed: D5.1 (K), L2.1, U3.2 (OUT)
unnamed: R5.2, RV2.2, RV2.3

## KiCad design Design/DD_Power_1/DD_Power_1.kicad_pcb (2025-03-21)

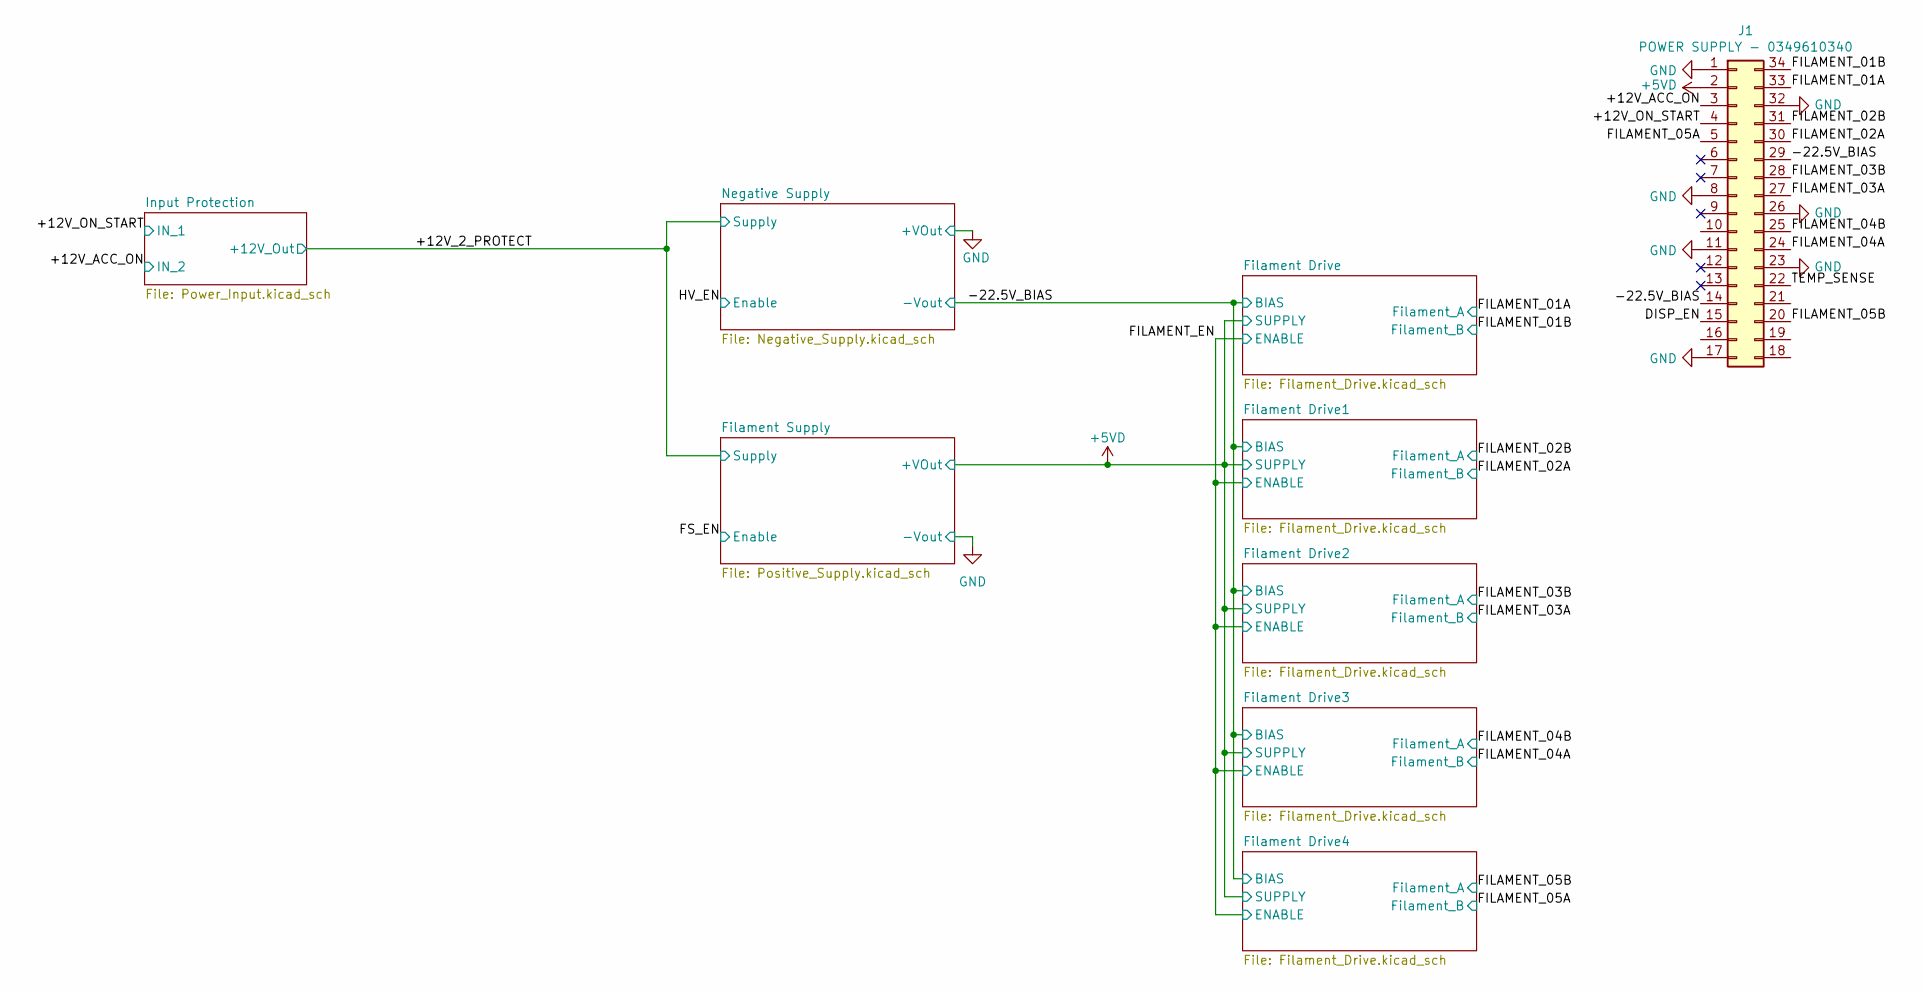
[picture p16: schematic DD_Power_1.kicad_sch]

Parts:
J1: POWER SUPPLY - 0349610340; 34961

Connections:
+5VD: J1.2; also elsewhere on the board
/+12V_ACC_ON: J1.3; also elsewhere on the board
/+12V_CONST: J1.21
/+12V_ON_START: J1.4; also elsewhere on the board
/-22.5V_BIAS: J1.14, J1.29; also elsewhere on the board
/DISP_EN: J1.15
/FILAMENT_01A: J1.33; also elsewhere on the board
/FILAMENT_01B: J1.34; also elsewhere on the board
/FILAMENT_02A: J1.30; also elsewhere on the board
/FILAMENT_02B: J1.31; also elsewhere on the board
/FILAMENT_03A: J1.27; also elsewhere on the board
/FILAMENT_03B: J1.28; also elsewhere on the board
/FILAMENT_04A: J1.24; also elsewhere on the board
/FILAMENT_04B: J1.25; also elsewhere on the board
/FILAMENT_05A: J1.5; also elsewhere on the board
/FILAMENT_05B: J1.20; also elsewhere on the board
/TEMP_SENSE: J1.22
GND: J1.1, J1.8, J1.11, J1.17, J1.23, J1.26, J1.32; also elsewhere on the board

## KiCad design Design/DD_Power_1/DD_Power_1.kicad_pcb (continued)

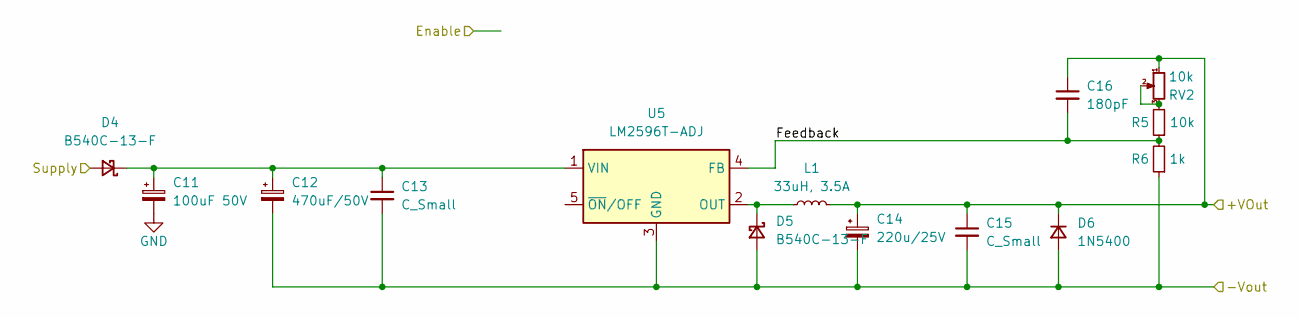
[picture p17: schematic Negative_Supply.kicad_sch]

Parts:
C11: 100uF 50V; CP_Radial_D8.0mm_P3.50mm
C12: 470uF/50V; CP_Radial_D12.5mm_P5.00mm
C13, C15: C_Small; C_0805_2012Metric_Pad1.18x1.45mm_HandSolder
C14: 220u/25V; CP_Radial_D6.3mm_P2.50mm
C16: 180pF; C_0805_2012Metric_Pad1.18x1.45mm_HandSolder
D4, D5: B540C-13-F; D_SMC
D6: 1N5400; D_SMC
L1: 33uH, 3.5A; L_Bourns_SRR1260
R5: 10k; R_0805_2012Metric_Pad1.20x1.40mm_HandSolder
R6: 1k; R_0805_2012Metric_Pad1.20x1.40mm_HandSolder
RV2: 10k; Potentiometer_Vishay_TS53YJ_Vertical
U5: LM2596T-ADJ; TO-220-5_P3.4x3.7mm_StaggerOdd_Lead3.8mm_Vertical

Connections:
/+12V_2_PROTECT: D4.2 (A); also elsewhere on the board
/-22.5V_BIAS: C12.2, C13.2, C14.2, C15.2, D5.2 (A), D6.2 (A), R6.1, U5.3 (GND); also elsewhere on the board
/Negative Supply/Feedback: C16.2, R5.1, R6.2, U5.4 (FB)
GND: C11.2, C14.1, C15.1, C16.1, D6.1 (K), L1.2, RV2.1; also elsewhere on the board
unnamed: C11.1, C12.1, C13.1, D4.1 (K), U5.1 (VIN)
unnamed: D5.1 (K), L1.1, U5.2 (OUT)
unnamed: R5.2, RV2.2, RV2.3

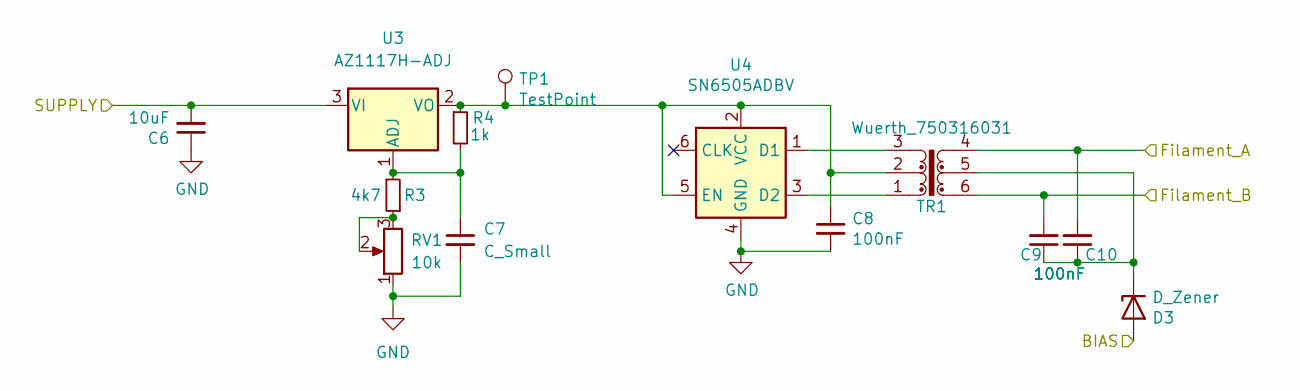
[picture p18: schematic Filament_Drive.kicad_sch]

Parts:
C6: 10uF; C_1206_3216Metric_Pad1.33x1.80mm_HandSolder
C7: C_Small; C_0805_2012Metric_Pad1.18x1.45mm_HandSolder
C8, C9, C10: 100nF; C_0805_2012Metric_Pad1.18x1.45mm_HandSolder
D3: D_Zener; D_SOD-123
R3: 4k7; R_0805_2012Metric_Pad1.20x1.40mm_HandSolder
R4: 1k; R_0805_2012Metric_Pad1.20x1.40mm_HandSolder
RV1: 10k; Potentiometer_Vishay_TS53YL_Vertical
TP1: TestPoint; TestPoint_2Pads_Pitch2.54mm_Drill0.8mm
TR1: Wuerth_750316031; Transformer_Wuerth_750315371
U3: AZ1117H-ADJ; SOT-223-3_TabPin2
U4: SN6505ADBV; SOT-23-6

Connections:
+5VD: C6.2, U3.3 (VI); also elsewhere on the board
/-22.5V_BIAS: D3.2 (A); also elsewhere on the board
/FILAMENT_01A: C10.2, TR1.4; also elsewhere on the board
/FILAMENT_01B: C9.2, TR1.6; also elsewhere on the board
GND: C6.1, C7.2, C8.2, RV1.1, U4.4 (GND); also elsewhere on the board
unnamed: C7.1, R3.2, R4.2, U3.1 (ADJ)
unnamed: C8.1, R4.1, TP1.1, TR1.2, U3.2 (VO), U4.2 (VCC), U4.5 (EN)
unnamed: C9.1, C10.1, D3.1 (K), TR1.5
unnamed: R3.1, RV1.2, RV1.3
unnamed: TR1.1, U4.3 (D2)
unnamed: TR1.3, U4.1 (D1)

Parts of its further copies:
C21, C26, C31, C36: 10uF; C_1206_3216Metric_Pad1.33x1.80mm_HandSolder
C22, C27, C32, C37: C_Small; C_0805_2012Metric_Pad1.18x1.45mm_HandSolder
C23, C24, C25, C28, C29, C30, C33, C34, C35, C38, C39, C40: 100nF; C_0805_2012Metric_Pad1.18x1.45mm_HandSolder
D8, D9, D10, D11: D_Zener; D_SOD-123
R7, R9, R11, R13: 4k7; R_0805_2012Metric_Pad1.20x1.40mm_HandSolder
R8, R10, R12, R14: 1k; R_0805_2012Metric_Pad1.20x1.40mm_HandSolder
RV3, RV4, RV5, RV6: 10k; Potentiometer_Vishay_TS53YL_Vertical
TP2, TP3, TP4, TP5: TestPoint; TestPoint_2Pads_Pitch2.54mm_Drill0.8mm
TR2, TR3, TR4, TR5: Wuerth_750316031; Transformer_Wuerth_750315371
U7, U9, U11, U13: AZ1117H-ADJ; SOT-223-3_TabPin2
U8, U10, U12, U14: SN6505ADBV; SOT-23-6

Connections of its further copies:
+5VD: C21.2, C26.2, C31.2, C36.2, U7.3 (VI), U9.3 (VI), U11.3 (VI), U13.3 (VI); also elsewhere on the board
/-22.5V_BIAS: D8.2 (A), D9.2 (A), D10.2 (A), D11.2 (A); also elsewhere on the board
/FILAMENT_02A: C24.2, TR2.6; also elsewhere on the board
/FILAMENT_02B: C25.2, TR2.4; also elsewhere on the board
/FILAMENT_03A: C29.2, TR3.6; also elsewhere on the board
/FILAMENT_03B: C30.2, TR3.4; also elsewhere on the board
/FILAMENT_04A: C34.2, TR4.6; also elsewhere on the board
/FILAMENT_04B: C35.2, TR4.4; also elsewhere on the board
/FILAMENT_05A: C39.2, TR5.6; also elsewhere on the board
/FILAMENT_05B: C40.2, TR5.4; also elsewhere on the board
GND: C21.1, C22.2, C23.2, C26.1, C27.2, C28.2, C31.1, C32.2, C33.2, C36.1, C37.2, C38.2, RV3.1, RV4.1, RV5.1, RV6.1, U8.4 (GND), U10.4 (GND), U12.4 (GND), U14.4 (GND); also elsewhere on the board
unnamed: C22.1, R7.2, R8.2, U7.1 (ADJ)
unnamed: C23.1, R8.1, TP2.1, TR2.2, U7.2 (VO), U8.2 (VCC), U8.5 (EN)
unnamed: C24.1, C25.1, D8.1 (K), TR2.5
unnamed: C27.1, R9.2, R10.2, U9.1 (ADJ)
unnamed: C28.1, R10.1, TP3.1, TR3.2, U9.2 (VO), U10.2 (VCC), U10.5 (EN)
unnamed: C29.1, C30.1, D9.1 (K), TR3.5
unnamed: C32.1, R11.2, R12.2, U11.1 (ADJ)
unnamed: C33.1, R12.1, TP4.1, TR4.2, U11.2 (VO), U12.2 (VCC), U12.5 (EN)
unnamed: C34.1, C35.1, D10.1 (K), TR4.5
unnamed: C37.1, R13.2, R14.2, U13.1 (ADJ)
unnamed: C38.1, R14.1, TP5.1, TR5.2, U13.2 (VO), U14.2 (VCC), U14.5 (EN)
unnamed: C39.1, C40.1, D11.1 (K), TR5.5
unnamed: R7.1, RV3.2, RV3.3
unnamed: R9.1, RV4.2, RV4.3
unnamed: R11.1, RV5.2, RV5.3
unnamed: R13.1, RV6.2, RV6.3
unnamed: TR2.1, U8.3 (D2)
unnamed: TR2.3, U8.1 (D1)
unnamed: TR3.1, U10.3 (D2)
unnamed: TR3.3, U10.1 (D1)
unnamed: TR4.1, U12.3 (D2)
unnamed: TR4.3, U12.1 (D1)
unnamed: TR5.1, U14.3 (D2)
unnamed: TR5.3, U14.1 (D1)


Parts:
C17: 100uF 50V; CP_Radial_D8.0mm_P3.50mm
C18, C20: C_Small; C_0805_2012Metric_Pad1.18x1.45mm_HandSolder
C19: 220u/25V; CP_Radial_D6.3mm_P2.50mm
D7: B540C-13-F; D_SMC
L2: 33uH, 3.5A; L_Bourns_SRR1260
U6: LM2596T-5; TO-220-5_P3.4x3.7mm_StaggerOdd_Lead3.8mm_Vertical

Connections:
+5VD: C19.1, C20.1, L2.2, U6.4 (FB); also elsewhere on the board
/+12V_2_PROTECT: C17.1, C18.1, U6.1 (VIN); also elsewhere on the board
GND: C17.2, C18.2, C19.2, C20.2, D7.2 (A), U6.3 (GND); also elsewhere on the board
unnamed: D7.1 (K), L2.1, U6.2 (OUT)


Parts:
C41: 100uF 50V; CP_Radial_D8.0mm_P3.50mm
C42: C_Small
D12: MBR20100CT-G1; TO-220-3_Vertical
D13: D_TVS; D_SMC
U15: L7815; TO-220-3_Vertical

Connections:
/+12V_2_PROTECT: U15.3 (OUT); also elsewhere on the board
/+12V_ACC_ON: D12.1 (A); also elsewhere on the board
/+12V_ON_START: D12.3 (A); also elsewhere on the board
GND: C41.2, C42.2, D13.1 (A1), U15.2 (GND); also elsewhere on the board
unnamed: C41.1, C42.1, D12.2 (K), D13.2 (A2), U15.1 (IN)



Board: 4 copper layers, 110.0 x 47.8 mm, 91 parts (57 on the bottom side), 52 nets.

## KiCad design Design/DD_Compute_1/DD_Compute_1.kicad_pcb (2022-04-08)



Board: 2 copper layers, 200.0 x 65.0 mm, 172 parts (5 on the bottom side), 226 nets.

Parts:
3.3V1, 5V_Analog1, 5V_Disp1, 5V_Logic1: TestPoint; TestPoint_Pad_D2.0mm
C1, C2, C3, C4, C5, C6, C7, C8, C10, C59, C65, C69: 100nF; C_0805_2012Metric
C9, C11, C12, C14, C15, C17, C18, C19, C20, C21, C22, C23, C24, C25, C26, C27, C28, C29, C30, C31, C32, C33, C34, C35, C36, C37, C38, C39, C40, C41, C42, C43, C44, C45, C46, C47, C48, C51, C53, C54, C67: 100n; C_0805_2012Metric
C13, C58, C60, C62, C64, C68: 1uF; C_0805_2012Metric
C16, C49, C50, C52: 10n; C_0805_2012Metric
C55, C56, C57, C63: 47uF; CP_Elec_5x5.3
C61, C66, C70: 10nF; C_0805_2012Metric
D1, D2, D3, D4, D5, D6, D7, D8, D9, D10, D11: 1N4148WS; D_SOD-323
F1, F2, F3: Polyfuse_Small; Fuse_1812_4532Metric_Pad1.30x3.40mm_HandSolder
GND1: TestPoint; TestPoint_2Pads_Pitch2.54mm_Drill0.8mm
J1: DISP. BOARD CONN 1 (1-20); PinSocket_1x20_P2.54mm_Vertical
J2: DISP. BOARD CONN 2 (21-40); PinSocket_1x20_P2.54mm_Vertical
J3: TRIP BOARD CONN 1 (1-10); JST_XH_B10B-XH-A_1x10_P2.50mm_Vertical
J4: TRIP BOARD CONN 2 (11-22); JST_XH_B12B-XH-A_1x12_P2.50mm_Vertical
J5: POWER SUPPLY - 0349580340; 34958
J6: CAR INTERFACE - 0349580340 - SIG; 34958
J7: CAR INTERFACE - 0349580341; 34958
J8: DISP_BOARD_CONN_3; JST_XH_B8B-XH-A_1x08_P2.50mm_Vertical
J9: ISOLATED OUPTUTS & POWER; PinHeader_2x03_P2.54mm_Vertical
J10, J11, J12: Conn_01x03; JST_XH_B4B-XH-A_1x04_P2.50mm_Vertical
J13: ISOLATED INPUTS; PinHeader_1x03_P2.54mm_Vertical
J14: ODOMETER MODULE; JST_XH_B3B-XH-A_1x03_P2.50mm_Vertical
R1: 47k; R_0805_2012Metric_Pad1.20x1.40mm_HandSolder
R2: 2.2k; R_0805_2012Metric_Pad1.20x1.40mm_HandSolder
R3: 47; R_Axial_DIN0414_L11.9mm_D4.5mm_P15.24mm_Horizontal
R4, R5: 1k; R_0805_2012Metric_Pad1.20x1.40mm_HandSolder
RN1, RN2, RN3, RN4, RN5, RN6, RN7, RN8, RN9, RN10, RN11, RN12, RN13, RN14, RN15, RN16, RN17, RN18, RN19, RN20, RN21, RN22, RN23, RN24: 4.7k; R_Array_Convex_4x0603
Rb1, Rb2: 75k 1%; R_0805_2012Metric_Pad1.20x1.40mm_HandSolder
Rt1, Rt6: 35.7k 1%; R_0805_2012Metric_Pad1.20x1.40mm_HandSolder
Rt2, Rt3, Rt4, Rt5: R; R_Axial_DIN0309_L9.0mm_D3.2mm_P12.70mm_Horizontal
Rt7, Rt8: 47k; R_0805_2012Metric
TH1: NTCG204AH473JT1; R_0805_2012Metric
U1, U4, U6, U7: 74HCT244D,653; SO-20_12.8x7.5mm_P1.27mm
U2: 74HCT00D,653; SO-14_3.9x8.65mm_P1.27mm
U3: TLE6250GV33; SSOP-8_3.9x5.05mm_P1.27mm
U5: Teensy3.6; Teensy35_36_centerpins
U8, U19, U20, U21: 74HC165D-Q100,118; SOIC-16_3.9x9.9mm_P1.27mm
U9: 25LC020AT-E/SN; SOIC-8_3.9x4.9mm_P1.27mm
U10, U27: VO0631T; SOIC-8_3.9x4.9mm_P1.27mm
U11, U14, U15, U16, U28, U29: SN74LV1T34DCK; SOT-353_SC-70-5
U12: MCP3008; SOIC-16_3.9x9.9mm_P1.27mm
U13: SN74AHC1G125DCK3; SOT-353_SC-70-5
U17, U18, U22, U23, U24, U25, U26: SRV05-4; SOT-23-6

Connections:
12V_Sense: RN2.2, Rb2.1, Rt6.2, U25.4
+3V3: 3.3V1.1, C7.1, C8.2, C30.1, C31.1, C32.1, C51.2, C53.2, J9.2, R1.2, RN1.5, RN1.6, RN1.7, RN1.8, Rt8.1, U3.5, U5.15, U5.26, U5.51, U5.75, U8.16, U9.3, U9.7, U9.8, U10.8, U13.5, U19.16, U20.16, U21.16, U27.8
+5V: 5V_Logic1.1, C1.1, C2.2, C3.1, C4.2, C5.2, C6.2, C13.1, C19.1, C20.1, C21.1, C55.1, C57.1, C60.1, C62.1, J5.10, J5.18, U1.20, U2.14, U3.3, U4.20, U5.53, U6.20, U7.20, U11.5, U12.16, U15.5, U16.5, U17.5, U18.5, U22.5, U23.5, U24.5, U25.5, U26.5
+5VA: 5V_Analog1.1, C54.1, C56.1, C58.1, C59.1, C61.1, J5.19, J6.8, J6.23, J9.3, R4.2, R5.2, RN7.3, RN7.4, Rt2.1, Rt3.1, Rt4.1, Rt5.1, Rt7.1, U12.15, U28.5
+5VD: 5V_Disp1.1, C18.1, C63.1, C64.1, C65.1, C66.1, C67.1, J1.3, J2.5, J2.6, J4.9, J5.2, J10.1, J11.1, J12.1, J14.3, U2.2, U2.4, U2.9, U2.13, U14.5, U29.5
+12V_ACC_ON: F1.2, J6.4
+12V_CONST: F3.1, J6.1, Rt6.1
+12V_ON_START: F2.2, J6.3
+12V_ON_START_B: J6.33, J8.8, R3.1
+12V_Security: J6.29, J8.5, RN7.1
/Illum_Data_Loop1: J10.3, J11.2
/Illum_Data_Loop2: J11.3, J12.2
/Illum_Data_Out: J10.2, U14.4
/Secondary_Warning_Input/ASCD_CruiseB: C23.2, RN4.7, RN5.7, U17.4, U19.4
/Secondary_Warning_Input/ASCD_OnB: C22.2, RN4.8, RN5.8, U17.6, U19.3
/Secondary_Warning_Input/ASCD_Set_Disp_1B: C24.2, RN4.6, RN5.6, U17.1, U19.5
/Secondary_Warning_Input/ASCD_Set_Disp_2B: C25.2, RN4.5, RN5.5, U17.3, U19.6
/Secondary_Warning_Input/Belt: C34.2, RN15.1, U20.11, U23.3
/Secondary_Warning_Input/Brake_1: C38.2, RN15.3, U20.13, U23.4
/Secondary_Warning_Input/Brake_2: C40.2, RN15.4, U20.14, U23.6
/Secondary_Warning_Input/Coolant: C41.2, RN19.8, U20.3, U24.3
/Secondary_Warning_Input/Door: C44.2, RN19.5, U20.6, U24.6
/Secondary_Warning_Input/Extra_HighB: C39.2, RN11.4, RN13.5, U21.3, U22.3
/Secondary_Warning_Input/Extra_Low_1B: C45.2, RN23.1, U21.11, U26.3
/Secondary_Warning_Input/Extra_Low_2B: C46.2, RN23.2, U21.12, U26.1
/Secondary_Warning_Input/Extra_Low_3B: C47.2, RN23.3, U21.13, U26.4
/Secondary_Warning_Input/Extra_Low_4B: C48.2, RN23.4, U21.14, U26.6
/Secondary_Warning_Input/Headlamp: C42.2, RN19.7, U20.4, U24.1
/Secondary_Warning_Input/Left_Turn: C35.2, RN11.2, RN13.7, U21.6, U22.4
/Secondary_Warning_Input/Main_Beam: C33.2, RN11.1, RN13.8, U21.5, U22.6
/Secondary_Warning_Input/Right_Turn: C37.2, RN11.3, RN13.6, U21.4, U22.1
/Secondary_Warning_Input/Sensor: C36.2, RN15.2, U20.12, U23.1
/Secondary_Warning_Input/Taillamp: C43.2, RN19.6, U20.5, U24.4
/Secondary_Warning_Input/Warn_ChargeB: C27.2, RN8.7, U18.1, U19.13
/Secondary_Warning_Input/Warn_FuelB: C28.2, RN8.6, U18.4, U19.12
/Secondary_Warning_Input/Warn_Oil_PressB: C29.2, RN8.5, U18.6, U19.11
/Secondary_Warning_Input/Warn_SecurityB: C26.2, RN8.8, U18.3, U19.14
/Warning_Extra_1: J7.26, RN22.8, RN23.8, RN24.1
/Warning_Extra_2: J7.27, RN22.7, RN23.7, RN24.2
/Warning_Extra_3: J7.28, RN22.6, RN23.6, RN24.3
/Warning_Extra_4: J7.29, RN22.5, RN23.5, RN24.4
ANALOG_EN: J5.16, U5.10
ASCD_Cruise: J6.13, RN6.2
ASCD_On: J6.12, J8.6, RN6.1
ASCD_Set_Disp_1: J6.14, RN6.3
ASCD_Set_Disp_2: J6.15, RN6.4
Bias_Grid_Anode: C68.1, C69.1, C70.1, J2.3, J4.11, J5.14, J5.29
Blanking_Control: R1.1, U5.7, U29.2
CAN_INH: U3.8, U5.23
CAN_RX: U3.4, U5.22
CAN_TX: U3.1, U5.21
CTL_IC31: U5.76, U7.2
Clock_1_(Time): J6.21, U3.7
Clock_2_(Time): J6.22, U3.6
Coil_Negative_(Tach): J6.6, J13.2, R2.2
DISP_EN: J5.15, U5.9
Disp_CTL_IC31: J4.6, U7.18
Disp_Mode_IC30: J4.10, U7.3
Disp_Reset_IC30: J4.1, U7.5
Disp_Reset_IC31: J4.8, U7.16
Disp_S0_IC30: J3.7, U6.3
Disp_S0_IC31: J3.1, U6.18
Disp_S1_IC30: J3.8, U6.5
Disp_S1_IC31: J3.2, U6.16
Disp_S2_IC30: J3.9, U6.7
Disp_S2_IC31: J3.3, U6.14
Disp_S3_IC30: J3.10, U6.9
Disp_S3_IC31: J3.4, U6.12
Disp_~WR~_IC30: J4.2, U7.7
Disp_~WR~_IC31: J4.5, U7.14
Display_Blank_Input: J1.1, U29.4
Display_CS_DrvRA4: J2.14, U4.16
Display_CS_DrvRA5: J2.15, U4.14
Display_CS_DrvRA7: J2.11, U4.5
Display_CS_DrvRA10: J2.13, U4.18
Display_CS_DrvRA12: J2.12, U4.3
Display_CS_Fuel_Lvl: J1.8, U1.5
Display_CS_Fuel_Qty: J1.4, U1.16
Display_CS_Oil: J1.5, U1.14
Display_CS_Temp: J1.6, U1.12
Display_CS_Volts: J1.7, U1.3
Display_LH_Main: J2.10, U4.7
Display_LH_Satellite: J1.10, U1.7
Display_SCK_Main: J2.16, U4.12
Display_SCK_Satellite: J1.2, U1.18
Display_SI_Main: J2.9, U4.9
Display_SI_Satellite: J1.11, U1.9
Extra_High_Input: J7.20, RN14.4
Filament_Fuel_A: J1.19, J5.33
Filament_Fuel_B: J1.20, J5.34
Filament_Speed_A: J1.17, J5.30
Filament_Speed_B: J1.18, J5.31
Filament_Sub_A: J1.13, J5.24
Filament_Sub_B: J1.14, J5.25
Filament_Tach_A: J1.15, J5.27
Filament_Tach_B: J1.16, J5.28
Filament_Trip_A: J3.5, J5.5
Filament_Trip_B: J3.6, J5.20
Fuel_Gauge_Main: J6.16, RN3.1, Rt5.2
Fuel_Gauge_Sub: J6.17, RN3.2, Rt4.2
Fuel_Injection_Pulse: C50.1, J6.20, J13.3, U10.3
Fuel_Injection_Pulse_Protect: J9.5, U5.47, U10.6
GND: C1.2, C2.1, C3.2, C4.1, C5.1, C6.1, C7.2, C8.1, C9.1, C10.1, C11.1, C12.1, C13.2, C14.1, C15.1, C16.1, C17.1, C18.2, C19.2, C20.2, C21.2, C22.1, C23.1, C24.1, C25.1, C26.1, C27.1, C28.1, C29.1, C30.2, C31.2, C32.2, C33.1, C34.1, C35.1, C36.1, C37.1, C38.1, C39.1, C40.1, C41.1, C42.1, C43.1, C44.1, C45.1, C46.1, C47.1, C48.1, C49.2, C51.1, C53.1, C54.2, C55.2, C56.2, C57.2, C58.2, C59.2, C60.2, C61.2, C62.2, C63.2, C64.2, C65.2, C66.2, C67.2, C68.2, C69.2, C70.2, D1.2, GND1.1, J2.1, J2.2, J4.12, J5.1, J5.8, J5.11, J5.17, J5.23, J5.26, J5.32, J6.2, J6.30, J6.32, J8.7, J9.1, J10.4, J11.4, J12.4, J14.1, RN4.1, RN4.2, RN4.3, RN4.4, RN9.3, RN9.4, RN16.5, RN16.6, RN16.7, RN16.8, RN20.5, RN20.6, RN20.7, RN20.8, RN24.5, RN24.6, RN24.7, RN24.8, Rb1.2, Rb2.2, TH1.2, U1.10, U2.7, U3.2, U4.10, U5.1, U5.27, U5.39, U5.74, U6.10, U7.8, U7.10, U7.11, U8.3, U8.4, U8.5, U8.6, U8.8, U8.10, U9.4, U10.2, U10.5, U11.3, U12.9, U12.14, U13.3, U14.3, U15.3, U16.3, U17.2, U18.2, U19.8, U20.8, U21.8, U22.2, U23.2, U24.2, U25.2, U26.2, U27.5, U28.3, U29.3
IC30_OE: U2.1, U5.43
IC31_OE: U2.5, U5.45
INT_TEMP_SENSE: Rt8.2, TH1.1, U5.50
Illum_Data: U5.30, U14.2
Illum_Sense: RN2.3, Rb1.1, Rt1.2, U25.1
Illumination_2: J6.7, Rt1.1
Indicator_Pilot_Common: J7.5, RN11.5, RN11.6, RN11.7, RN11.8
Indicator_Pilot_Left: J7.22, RN14.2
Indicator_Pilot_Main: J7.23, RN14.1
Indicator_Pilot_Right: J7.21, RN14.3
Main_Enable: U2.12, U5.44
Manifold_Pressure: J6.11, RN2.4
Mode_IC30: U5.67, U7.17
unnamed: C9.2, RN2.8, U12.1
unnamed: C10.2, RN3.8, U12.5
unnamed: C11.2, RN2.7, U12.2
unnamed: C12.2, RN3.7, U12.6
unnamed: C14.2, RN2.6, U12.3
unnamed: C15.2, RN3.6, U12.7
unnamed: C16.2, RN2.5, U12.4
unnamed: C17.2, RN3.5, U12.8
unnamed: C49.1, D1.1, R2.1, U10.1
unnamed: C50.2, R4.1, U10.4
unnamed: C52.2, R5.1, U27.1
unnamed: D2.2, D11.2, J8.2
unnamed: F1.1, J5.3
unnamed: F2.1, J5.4
unnamed: F3.2, J5.21
unnamed: RN5.1, RN6.8
unnamed: RN5.2, RN6.7
unnamed: RN5.3, RN6.6
unnamed: RN5.4, RN6.5
unnamed: RN7.7, RN9.2
unnamed: RN8.1, RN9.5, RN9.8
unnamed: RN8.2, RN9.6, RN9.7
unnamed: RN10.5, RN12.4
unnamed: RN10.6, RN12.3
unnamed: RN10.7, RN12.2
unnamed: RN10.8, RN12.1
unnamed: RN13.1, RN14.8
unnamed: RN13.2, RN14.7
unnamed: RN13.3, RN14.6
unnamed: RN13.4, RN14.5
unnamed: RN17.5, RN18.4
unnamed: RN17.6, RN18.3
unnamed: RN17.7, RN18.2
unnamed: RN17.8, RN18.1
unnamed: RN21.5, RN22.4
unnamed: RN21.6, RN22.3
unnamed: RN21.7, RN22.2
unnamed: RN21.8, RN22.1
unnamed: U1.1, U1.19, U2.8
unnamed: U2.3, U6.19, U7.19
unnamed: U2.6, U6.1, U7.1
unnamed: U2.11, U4.1, U4.19
unnamed: U11.4, U12.10
unnamed: U12.11, U16.4
unnamed: U12.12, U13.2
unnamed: U12.13, U15.4
unnamed: U19.10, U20.9
unnamed: U20.10, U21.9
ODOMETER_SIGNAL: J14.2, U5.34
Oil_Pressure: J6.18, RN3.3, Rt3.2
PS_TEMP_SENSE: J5.22, RN2.1, Rt7.2
Reset_IC30: U5.68, U7.15
Reset_IC31: U5.77, U7.4
S0_IC30: U5.86, U6.17
S0_IC31: U5.82, U6.2
S1_IC30: U5.85, U6.15
S1_IC31: U5.81, U6.4
S2_IC30: U5.84, U6.13
S2_IC31: U5.80, U6.6
S3_IC30: U5.83, U6.11
S3_IC31: U5.79, U6.8
SPI1_CS0: U1.15, U5.5
SPI1_CS1: U1.17, U5.6
SPI1_CS2: U1.8, U5.12
SPI1_CS3: U1.6, U5.11
SPI1_CS4: U1.4, U5.8
SPI1_CS5: U5.42, U8.15
SPI1_LH: U1.13, U5.4, U8.1
SPI1_MISO: U5.3, U8.9
SPI1_MOSI: U1.11, U5.2
SPI1_SCK: U1.2, U5.24, U8.2
SPI2_CS0: U4.2, U5.17
SPI2_CS1: U4.4, U5.16
SPI2_CS2: U4.6, U5.14
SPI2_CS3: U4.15, U5.19
SPI2_CS4: U4.17, U5.18
SPI2_CS5: U5.20, U9.1
SPI2_CS6: U5.70, U11.2, U13.1
SPI2_CS7: U5.32, U19.15, U20.15, U21.15
SPI2_LH: U4.13, U5.13, U19.1, U20.1, U21.1
SPI2_MISO: U5.72, U9.2, U13.4, U19.9
SPI2_MOSI: U4.11, U5.71, U9.5, U16.2
SPI2_SCK: U4.8, U5.73, U9.6, U15.2, U19.2, U20.2, U21.2
SW_Indicated_Spd: J1.12, RN1.4, U8.11
SW_MPH-MPG: J4.7, RN1.1, U8.14
SW_Trip_A: J4.4, RN1.2, U8.13
SW_Trip_B: J4.3, RN1.3, U8.12
Satellite_Enable: U2.10, U5.46
Speed_Out: U5.33, U28.2
Speed_Sensor_In: C52.1, J6.9, J13.1, U27.2
Speed_Sensor_Protect: J9.4, U5.49, U27.7
Speed_Signal_Out: J6.10, U28.4
Tach_Protect: J9.6, U5.48, U10.7
Warning-12V-Supply: J7.6, RN10.1, RN10.2, RN10.3, RN10.4, RN17.1, RN17.2, RN17.3, RN17.4, RN21.1, RN21.2, RN21.3, RN21.4
Warning_Belt: D4.2, J7.11, RN12.7, RN15.7, RN16.2
Warning_Brake: D5.2, J7.10, RN12.6, RN15.6, RN16.3
Warning_Brake_2: D6.2, J7.9, RN12.5, RN15.5, RN16.4
Warning_Bulb_Check: D3.1, D4.1, D5.1, D6.1, D7.1, D8.1, D9.1, D10.1, J7.18
Warning_Charge: D11.1, J6.25, J8.3, R3.2, RN7.2
Warning_Coolant: D7.2, J7.14, RN18.8, RN19.1, RN20.1
Warning_Door: D10.2, J7.16, RN18.5, RN19.4, RN20.4
Warning_Fuel_Level: D2.1, J6.26, RN7.6, RN8.3
Warning_Headlamp: D8.2, J7.13, RN18.7, RN19.2, RN20.2
Warning_Oil_Pressure: J6.27, J8.1, RN7.5, RN8.4
Warning_Security: J6.28, J8.4, RN7.8, RN9.1
Warning_Sensor: D3.2, J7.12, RN12.8, RN15.8, RN16.1
Warning_Taillamp: D9.2, J7.15, RN18.6, RN19.3, RN20.3
Water_Temperature: J6.19, RN3.4, Rt2.2
~WR~_IC30: U5.69, U7.13
~WR~_IC31: U5.78, U7.6

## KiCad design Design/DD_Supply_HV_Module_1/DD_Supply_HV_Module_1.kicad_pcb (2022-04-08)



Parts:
C1: 680nF 7.125mOhm; C_0805_2012Metric_Pad1.18x1.45mm_HandSolder
C2: 100nF 39.064mOhm; C_0805_2012Metric_Pad1.18x1.45mm_HandSolder
C3, C8: 100nF 1mOhm; C_0805_2012Metric_Pad1.18x1.45mm_HandSolder
C4: 22nF 1mOhm; C_0805_2012Metric_Pad1.18x1.45mm_HandSolder
C5: 2.2uF 1mOhm; C_0805_2012Metric_Pad1.18x1.45mm_HandSolder
C6: 130pF 0Ohm; C_0805_2012Metric_Pad1.18x1.45mm_HandSolder
C7: 33nF 1mOhm; C_0805_2012Metric_Pad1.18x1.45mm_HandSolder
C9: 20pF 0Ohm; C_0805_2012Metric_Pad1.18x1.45mm_HandSolder
C10: 390pF 0Ohm; C_0805_2012Metric_Pad1.18x1.45mm_HandSolder
C11: 680nF 9.732mOhm; C_0805_2012Metric_Pad1.18x1.45mm_HandSolder
C12: 15uF 40mOhm; CP_Elec_8x11.9
C13: 1uF 11.416mOhm; C_0805_2012Metric_Pad1.18x1.45mm_HandSolder
D1: 620mV 2A; SMP_DO-220AA
J1: Conn_01x03; PinHeader_1x03_P2.54mm_Vertical
J2: Conn_01x07; PinHeader_1x07_P2.54mm_Vertical
L1: 8.2uH 55mOhm; L_Bourns_SRN6045TA
M1: CSD19538Q2; Texas_DQK
R1: 10kOhm; R_0805_2012Metric_Pad1.20x1.40mm_HandSolder
R2: 1.74kOhm; R_0805_2012Metric_Pad1.20x1.40mm_HandSolder
R3: 92kOhm; R_0805_2012Metric_Pad1.20x1.40mm_HandSolder
R4: 4.75kOhm; R_0805_2012Metric_Pad1.20x1.40mm_HandSolder
R5: 66.5kOhm; R_0805_2012Metric_Pad1.20x1.40mm_HandSolder
R6: 30mOhm; R_1206_3216Metric_Pad1.30x1.75mm_HandSolder
R7: 28.7kOhm; R_0805_2012Metric_Pad1.20x1.40mm_HandSolder
R8: 1.65kOhm; R_0805_2012Metric_Pad1.20x1.40mm_HandSolder
U1: LM5088-1; HTSSOP-16-1EP_4.4x5mm_P0.65mm_EP3.4x5mm_Mask3x3mm_ThermalVi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

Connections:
+12V_Protect: C1.1, C2.1, C11.1, J1.1, M1.1 (D), M1.2 (D), M1.5 (D), M1.6 (D), M1.8 (D), R1.1, U1.1 (VIN)
-22V_Out: C3.2, C4.2, C5.2, C6.2, C7.2, C11.2, C12.2, C13.2, J1.3, J2.4, J2.5, J2.6, J2.7, R2.2, R4.2, R6.2, R8.2, U1.6 (GND), U1.11 (CSG), U1.17 (PGND)
ENABLE: C3.1, J2.1, R1.2, R2.1, U1.2 (EN)
GND: C1.2, C2.2, C12.1, C13.1, J1.2, J2.2, J2.3, L1.2, R7.1, U1.9 (OUT)
unnamed: C4.1, U1.10 (DITH)
unnamed: C5.1, R3.1, U1.16 (VCC)
unnamed: C6.1, R3.2, U1.4 (RAMP)
unnamed: C7.1, U1.3 (SS)
unnamed: C8.1, D1.1 (K), L1.1, M1.4 (S), M1.7 (S), U1.13 (SW)
unnamed: C8.2, U1.15 (BOOT)
unnamed: C9.2, R5.1, U1.7 (COMP)
unnamed: C9.1, C10.1, R7.2, R8.1, U1.8 (FB)
unnamed: C10.2, R5.2
unnamed: D1.2 (A), R6.1, U1.12 (CS)
unnamed: M1.3 (G), U1.14 (HG)
unnamed: R4.1, U1.5 (RT/SYNC)


Board: 2 copper layers, 48.3 x 27.9 mm, 27 parts (0 on the bottom side), 16 nets.

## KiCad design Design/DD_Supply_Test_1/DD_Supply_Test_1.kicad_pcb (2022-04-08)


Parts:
BIAS_A1: TestPoint; TestPoint_Pad_D2.0mm
BIAS_F1: TestPoint; TestPoint_Pad_D2.0mm
C1, C3, C4, C5, C6, C7, C8, C9, C10, C11, C12, C25, C26, C27, C28, C29, C30, C31, C32, C33, C34, C35, C36, C37, C38: C1206C106M3PACTU; C_1206_3216Metric_Pad1.33x1.80mm_HandSolder
C13: 12pF; C_1206_3216Metric_Pad1.33x1.80mm_HandSolder
C14: 15nF; C_1206_3216Metric_Pad1.33x1.80mm_HandSolder
C15: 1uF; C_1206_3216Metric_Pad1.33x1.80mm_HandSolder
C16: 270nF; C_1206_3216Metric_Pad1.33x1.80mm_HandSolder
C17, C18, C19, C20: 1uF; CP_EIA-7132-28_AVX-C_Pad2.72x3.50mm_HandSolder
C21, C23: EEE-FK1V151P; CP_Elec_8x10.5
C22, C24: 16SEPC100MW+S; CP_Radial_D6.3mm_P2.50mm
F0_SUP1, F1_SUP1, F2_SUP1, F3_SUP1, F4_SUP1: TestPoint; TestPoint_Pad_D2.0mm
FD_SUP1: TestPoint; TestPoint_Pad_D2.0mm
J1: Conn_01x04; PinHeader_1x04_P2.54mm_Vertical
J2: Conn_01x9; PinHeader_1x09_P2.54mm_Vertical
J3: Conn_01x03; PinHeader_1x03_P2.54mm_Vertical
L1: 5.6uH; L_12x12mm_H8mm
Q1, Q2: IPD50N06S4L-12; TO-252-2
R1, R2, R3, R4, R5: TS53YL104MR10; Potentiometer_Vishay_TS53YL_Vertical
R6: 10K 1%; R_1206_3216Metric_Pad1.30x1.75mm_HandSolder
R7, R8, R9, R10: 30K 1%; R_1206_3216Metric_Pad1.30x1.75mm_HandSolder
R11: 20k 1%; R_1206_3216Metric_Pad1.30x1.75mm_HandSolder
R12: 6.65k 1%; R_1206_3216Metric_Pad1.30x1.75mm_HandSolder
R13: 1k 1%; R_1206_3216Metric_Pad1.30x1.75mm_HandSolder
R14, R15: 2K; R_1206_3216Metric_Pad1.30x1.75mm_HandSolder
R16, R17: 120R; R_1206_3216Metric_Pad1.30x1.75mm_HandSolder
TR1, TR2, TR3, TR4, TR5: Wuerth_750315371; Transformer_Wuerth_750315371
U2, U3, U4, U5, U6: TPS7A7001DDA; TI_SO-PowerPAD-8
U7, U8, U9, U10, U11: SN6505ADBV; SOT-23-6
U13: MC34063AD; SOIC-8_3.9x4.9mm_P1.27mm
U14: TLF51801ELV; SSOP-14_5.3x6.2mm_P0.65mm
U15, U16: LM337_SOT223; SOT-223-3_TabPin2

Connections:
FD_Enable: J1.2, U7.5 (EN), U8.5 (EN), U9.5 (EN), U10.5 (EN), U11.5 (EN), U14.3 (EN); also elsewhere on the board
FD_FB: U14.7 (FB)
FD_Supply: C22.1, C24.1, C29.2, C30.2, C31.2, C32.2, C33.2, FD_SUP1.1, L1.2, U2.2 (EN), U2.3 (IN), U3.2 (EN), U3.3 (IN), U4.2 (EN), U4.3 (IN), U5.2 (EN), U5.3 (IN), U6.2 (EN), U6.3 (IN)
Filament_0_Out_A: C3.1, J2.1, TR1.6
Filament_0_Out_B: C7.1, J2.2, TR1.4
Filament_1_Out_A: C12.2, J2.3, TR5.3; also elsewhere on the board
Filament_1_Out_B: C11.2, J2.4, TR5.1; also elsewhere on the board
Filament_2_Out_A: C4.1, J2.5, TR2.6
Filament_2_Out_B: C8.1, J2.6, TR2.4
Filament_3_Out_A: C5.1, J2.7, TR3.6
Filament_3_Out_B: C9.1, J2.8, TR3.4
Filament_4_Out_A: C10.1, J3.1, TR4.1
Filament_4_Out_B: C6.1, J3.2, TR4.3
Filament_Bias: BIAS_F1.1, C3.2, C4.2, C5.2, C6.2, C7.2, C8.2, C9.2, C10.2, C11.1, C12.1, C20.2, C23.2, R17.2, TR1.5, TR2.5, TR3.5, TR4.2, TR5.2, U16.3 (VO); also elsewhere on the board
GND: C1.1, C13.2, C14.2, C15.2, C17.1, C18.1, C19.1, C20.1, C21.1, C22.2, C23.1, C24.2, C25.1, C26.1, C27.1, C28.1, C29.1, C30.1, C31.1, C32.1, C33.1, C34.1, C35.1, C36.1, C37.1, C38.1, J1.1, Q2.3 (S), R1.2, R2.2, R3.2, R4.2, R5.2, R11.2, R14.1, R15.1, U2.8 (GND), U2.9 (EP), U3.8 (GND), U3.9 (EP), U4.8 (GND), U4.9 (EP), U5.8 (GND), U5.9 (EP), U6.8 (GND), U6.9 (EP), U7.4 (GND), U8.4 (GND), U9.4 (GND), U10.4 (GND), U11.4 (GND), U13.4 (GND), U14.4 (GND), U14.8 (PGND); also elsewhere on the board
Grid_Anode_Bias: BIAS_A1.1, C19.2, C21.2, J2.9, J3.3, R16.2, U15.3 (VO)
HV_Enable: J1.3; also elsewhere on the board
unnamed 17: C1.2, C34.2, F1_SUP1.1, R6.2, TR5.5, U2.6 (OUT), U11.2 (VCC); also elsewhere on the board
unnamed: C13.1, R12.1, U14.6 (COMP)
unnamed: C14.1, R12.2
unnamed: C15.1, U14.1 (IVCC)
unnamed: C16.1, U14.12 (BTS)
unnamed: C16.2, L1.1, Q1.3 (S), Q2.2 (D), U14.10 (BUO), U14.13 (sense_low)
unnamed: C17.2, C18.2, U15.2 (VI), U16.2 (VI)
unnamed: C25.2, C35.2, F0_SUP1.1, R7.2, TR1.2, U3.6 (OUT), U7.2 (VCC)
unnamed: C26.2, C36.2, F2_SUP1.1, R8.2, TR2.2, U4.6 (OUT), U8.2 (VCC)
unnamed: C27.2, C37.2, F3_SUP1.1, R9.2, TR3.2, U5.6 (OUT), U9.2 (VCC)
unnamed: C28.2, C38.2, F4_SUP1.1, R10.2, TR4.5, U6.6 (OUT), U10.2 (VCC)
unnamed 28: U13.5 (Vfb); also elsewhere on the board
unnamed: Q1.1 (G), U14.11 (UG)
unnamed: Q2.1 (G), U14.9 (LG)
unnamed: R1.1, R6.1, U2.7 (FB)
unnamed: R2.1, R7.1, U3.7 (FB)
unnamed: R3.1, R8.1, U4.7 (FB)
unnamed: R4.1, R9.1, U5.7 (FB)
unnamed: R5.1, R10.1, U6.7 (FB)
unnamed: R11.1, U14.5 (SYNC)
unnamed: R13.2, U14.14 (sense_high)
unnamed: R14.2, R16.1, U15.1 (ADJ)
unnamed: R15.2, R17.1, U16.1 (ADJ)
unnamed: TR1.1, U7.3 (D2)
unnamed: TR1.3, U7.1 (D1)
unnamed: TR2.1, U8.3 (D2)
unnamed: TR2.3, U8.1 (D1)
unnamed: TR3.1, U9.3 (D2)
unnamed: TR3.3, U9.1 (D1)
unnamed: TR4.4, U10.3 (D2)
unnamed: TR4.6, U10.1 (D1)
unnamed: TR5.4, U11.3 (D2)
unnamed: TR5.6, U11.1 (D1)
unnamed 79: U11.6 (CLK); also elsewhere on the board

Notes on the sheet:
HIGH CURRENT FILAMENT DRIVER (TACHOMETER) [FILAMENT 1]
INPUT/OUTPUT
INTERMEDIATE CURRENT FILAMENT DRIVER [FILAMENT 4]
INTERMEDIATE CURRENT FILAMENT DRIVER [FILAMENT 3]
INTERMEDIATE CURRENT FILAMENT DRIVER [FILAMENT 2]
INTERMEDIATE CURRENT FILAMENT DRIVER [FILAMENT 0]
BIAS VOLTAGE GENERATION
FILAMENT DRIVE PREREGULATOR (6-6.5V FD_Supply)
TOPOLOGY ORIGNATES FROM https://e2e.ti.com/support/isolation/f/1013/p/924970/3420368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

Board: 2 copper layers, 92 parts (0 on the bottom side), 53 nets.

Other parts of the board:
C2: C1206C106M3PACTU; C_1206_3216Metric_Pad1.33x1.80mm_HandSolder
D1: 1N4148; D_DO-35_SOD27_P7.62mm_Horizontal
TR6: Wuerth_750315371; Transformer_Wuerth_750315371
U1: LM555xM; SOIC-8_3.9x4.9mm_P1.27mm
U12: SN6505ADBV; SOT-23-6

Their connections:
FD_Enable: U12.5; also elsewhere on the board
Filament_1_Out_A: TR6.6; also elsewhere on the board
Filament_1_Out_B: TR6.4; also elsewhere on the board
Filament_Bias: TR6.5; also elsewhere on the board
GND: C2.1, U12.4; also elsewhere on the board
HV_Enable: D1.2; also elsewhere on the board
unnamed 17: C2.2, TR6.2, U12.2; also elsewhere on the board
unnamed 28: D1.1; also elsewhere on the board
unnamed: TR6.1, U12.3
unnamed: TR6.3, U12.1
unnamed 79: U12.6; also elsewhere on the board

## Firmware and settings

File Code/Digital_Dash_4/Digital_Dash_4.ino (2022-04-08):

// This is the master code for digital dash conversion project
// It is targeted at board DD-Compute-E Rev 1 for teensy 3.5
// This interfaces with a 1984 Nissan 300zx Digital cluster.

#include <SPI.h>
#include <MCP_ADC_Teensy.h>
#include <LedDisplay.h>
#include <FreqMeasureMulti.h>
#include <ACAN.h>
#include <WS2812Serial.h>


// Pin definitions:
// Shift Register Enables
#define IC30_OE 16
#define IC31_OE 18
#define Main_OE 17
#define Satellite_OE 19

// Power Supply Enables
#define PWR_DISP_EN  7
#define PWR_ANALOG_EN 8

// SPI bus information
#define SPI1_LH 2
#define SPI1_SCK 32
#define SPI1_MISO 1
#define SPI1_MOSI 0

#define CS_BTN 15 //1x 74HC165D
#define CS_DISP_FUEL 3
#define CS_DISP_VOLT 4
#define CS_DISP_TEMP 10
#define CS_DISP_OIL 9
#define CS_DISP_FUEL2 6

#define SPI2_LH 11
#define SPI2_SCK 46
#define SPI2_MISO 45
#define SPI2_MOSI 44

#define CS_ADC 43 //MCP3008
#define CS_DDC 35 //3x 74HC165D
#define CS_EEPROM 15 //25LC020AT-E
#define CS_TACHH 25 // tach rpm?
#define CS_SPEED 24 //speed?
#define CS_SPEEDH 12 //speed small
#define CS_TACH 27 //tach numbers
#define CS_TACHV 26 // tach load?

// Other outputs
#define ILLUM_DATA  33 //neopixels
#define ODO_PULSE 37
#define SPEED_PULSE 36
#define BLANK_CONTROL 5

//CANbus
#define CAN_INH 31
#define CAN_RX 30
#define CAN_TX 29

//Other inputs (freq and analog [on-board temp])
#define SPEED_IN 22
#define TACH_IN 21
#define FUEL_IN 20
#define BOARD_TEMP A9

//trip meter character inputs
#define IC30_S0 57
#define IC30_S1 56
#define IC30_S2 55
#define IC30_S3 54

#define IC31_S0 53
#define IC31_S1 52
#define IC31_S2 51
#define IC31_S3 50

#define IC31_WR 49
#define IC31_RST 48
#define IC31_CTL 47

#define IC30_WR 42
#define IC30_RST 41
#define IC30_MODE 40

#define ODO_DATA 37
#define ODO_CLK 34
#define ODO_RS 38
#define ODO_RESET 39 //?
#define ODO_ENABLE 14 //?
#define ODO_LENGTH 16

//communication speeds
#define CAN_BITRATE 500000
#define SPI_CLK_ADC 1000000
#define SPI_CLK_DISPLAY 500000
#define SPI_CLK_SHIFT 1000000

//mins & maxes
#define FUEL_MIN 0 //us gal
#define FUEL_MAX 20
#define TEMP_MIN 50 //Degrees Celsius
#define TEMP_MAX 130 //Degrees Celsius
#define OIL_MIN 0 //kg/cm^2
#define OIL_MAX 6 //kg/cm^2
#define VOLTS_MIN 7
#define VOLTS_MAX 18
#define TACH_MIN 0 //rpm
#define TACH_MAX 7000 //rpm
#define SPEED_MIN 28 //MPH
#define SPEED_MAX 78

// declare components
MCP3008 myADC;
FreqMeasureMulti fmmInjectionPulse;
FreqMeasureMulti fmmTachometer;
FreqMeasureMulti fmmSpeedometer;


// SPI Settings
SPISettings scDisplay(SPI_CLK_DISPLAY, MSBFIRST, SPI_MODE3);
SPISettings scADC(SPI_CLK_ADC, MSBFIRST, SPI_MODE0);
SPISettings scInputs(SPI_CLK_SHIFT, MSBFIRST, SPI_MODE0);

LedDisplay ldOdometer(ODO_DATA, ODO_RS, ODO_CLK, ODO_ENABLE, ODO_RESET, ODO_LENGTH);

// global vars
byte stateButtons;
byte stateDiscrete[3];
uint16_t adcTempPower;
uint16_t adcVolts;
uint16_t adcIllum;
uint16_t adcPressureManifold;
uint16_t adcFuelMain;
uint16_t adcFuelSub;
uint16_t adcPressureOil;
uint16_t adcTempWater;
uint16_t adcTempInt;

boolean newData = false;
const byte numChars = 32;
char receivedChars[numChars];

byte dataOut[3];
int CSPin;

const byte Chars7Seg[16] {
  0b00111111, //0
  0b00000110, //1
  0b01011011, //2
  0b01001111, //3
  0b01100110, //4
  0b01101101, //5
  0b01111101, //6
  0b00000111, //7
  0b01111111, //8
  0b01101111, //9
  0b01110111, //a
  0b01111100, //b
  0b00111001, //c
  0b01011110, //d
  0b01111001, //e
  0b01110001  //F
};

void setup() {
  // put your setup code here, to run once:
  Serial.begin(9600);
  while (!Serial) {
    delay(10);
  }

  Serial.println("Z31DigiDash Test Stub No. 5");
  Serial.println("It's like Test Stub No. 4, Except I still have the code!");

  //configure all I/O pins & set to known state
  Serial.print("Pin Config...");
  pinMode(IC30_OE, OUTPUT);
  pinMode(IC31_OE, OUTPUT);
  pinMode(Main_OE, OUTPUT);
  pinMode(Satellite_OE, OUTPUT);

  digitalWrite(IC30_OE, LOW);
  digitalWrite(IC31_OE, LOW);
  digitalWrite(Main_OE, LOW);
  digitalWrite(Satellite_OE, LOW);


  pinMode(PWR_DISP_EN, OUTPUT);
  pinMode(PWR_ANALOG_EN, OUTPUT);

  digitalWrite(PWR_DISP_EN, LOW);
  digitalWrite(PWR_ANALOG_EN, LOW);


  pinMode(SPI1_LH, OUTPUT);
  pinMode(SPI1_SCK, OUTPUT);
  pinMode(SPI1_MOSI, OUTPUT);
  pinMode(SPI1_MISO, INPUT);
  pinMode(SPI2_LH, OUTPUT);
  pinMode(SPI2_SCK, OUTPUT);
  pinMode(SPI2_MOSI, OUTPUT);
  pinMode(SPI2_MISO, INPUT);


  pinMode(CS_BTN, OUTPUT);
  pinMode(CS_DISP_FUEL, OUTPUT);
  pinMode(CS_DISP_VOLT, OUTPUT);
  pinMode(CS_DISP_TEMP, OUTPUT);
  pinMode(CS_DISP_OIL, OUTPUT);
  pinMode(CS_DISP_FUEL2, OUTPUT);

  digitalWrite(CS_BTN, HIGH);
  digitalWrite(CS_DISP_FUEL, HIGH);
  digitalWrite(CS_DISP_VOLT, HIGH);
  digitalWrite(CS_DISP_TEMP, HIGH);
  digitalWrite(CS_DISP_OIL, HIGH);
  digitalWrite(CS_DISP_FUEL2, HIGH);


  pinMode(CS_ADC, OUTPUT);
  pinMode(CS_DDC, OUTPUT);
  // pinMode(CS_EEPROM, OUTPUT);
  pinMode(CS_TACHH, OUTPUT);
  pinMode(CS_TACHV, OUTPUT);
  pinMode(CS_TACH, OUTPUT);
  pinMode(CS_SPEED, OUTPUT);
  pinMode(CS_SPEEDH, OUTPUT);

  digitalWrite(CS_ADC, HIGH);
  digitalWrite(CS_DDC, HIGH);
  // pinMode(CS_EEPROM, OUTPUT);
  digitalWrite(CS_TACHH, HIGH);
  digitalWrite(CS_TACHV, HIGH);
  digitalWrite(CS_TACH, HIGH);
  digitalWrite(CS_SPEED, HIGH);
  digitalWrite(CS_SPEEDH, HIGH);


  pinMode(ILLUM_DATA, OUTPUT);
  pinMode(ODO_PULSE, OUTPUT);
  pinMode(SPEED_PULSE, OUTPUT);
  pinMode(BLANK_CONTROL, OUTPUT);

  digitalWrite(ILLUM_DATA, LOW);
  digitalWrite(ODO_PULSE, LOW);
  digitalWrite(SPEED_PULSE, LOW);
  digitalWrite(BLANK_CONTROL, LOW);

  pinMode(SPEED_IN, INPUT);
  pinMode(TACH_IN, INPUT);
  pinMode(FUEL_IN, INPUT);
  pinMode(BOARD_TEMP, INPUT);

  pinMode(CAN_INH, OUTPUT);
  digitalWrite(CAN_INH, HIGH);

  pinMode(ODO_DATA, OUTPUT);
  pinMode(ODO_CLK, OUTPUT);
  pinMode(ODO_RS, OUTPUT);
  pinMode(ODO_RESET, OUTPUT);
  pinMode(ODO_ENABLE, OUTPUT);

  Serial.println("OK");


  //Configure FreqMeasure Pins
  Serial.print("Config Frequency Inputs...");
  fmmInjectionPulse.begin(FUEL_IN);
  fmmTachometer.begin(TACH_IN);
  fmmSpeedometer.begin(SPEED_IN);
  Serial.println("OK");

  Serial.print("Config SPI...");
  SPI1.begin();
  SPI1.setMOSI(SPI1_MOSI);
  SPI1.setMISO(SPI1_MISO);
  SPI1.setSCK(SPI1_SCK);

  SPI2.begin();
  SPI2.setMOSI(SPI2_MOSI);
  SPI2.setMISO(SPI2_MISO);
  SPI2.setSCK(SPI2_SCK);
  Serial.println("OK");

  //Configure ADC
  Serial.println("Config ADC...");
  myADC.begin(CS_ADC);
  myADC.setSPIconfig(scADC);
  Serial.println("ADC\tCHAN\tMAXVALUE");
  Serial.print("myADC\t");
  Serial.print(myADC.channels()); Serial.print("\t");
  Serial.println(myADC.maxValue());
  Serial.println("OK");

  //Configure CAN
  Serial.print("Config CAN...");
  ACANSettings settingsCan(CAN_BITRATE);
  settingsCan.mRxPinHasInternalPullUp = true;
  settingsCan.mTxPinIsOpenCollector = true;
  settingsCan.mUseAlternateTxPin = true;
  settingsCan.mUseAlternateRxPin = true;
  digitalWrite(CAN_INH, LOW);
  const uint32_t errorCode = ACAN::can0.begin(settingsCan);
  if (0 == errorCode) {
    Serial.println("OK");
  }
  else {
    Serial.print("FAILED: can0: 0x");
    Serial.println(errorCode, HEX);
  }

  //led display
  Serial.print("Configure ODO Display...");
  ldOdometer.begin();
  ldOdometer.setBrightness(15);
  ldOdometer.home();
  ldOdometer.print("        Hello!");
  Serial.println("OK");


  //enable power supply & declare completion
  Serial.print("Enabling the power supply...");
  digitalWrite(PWR_DISP_EN, HIGH);
  digitalWrite(PWR_ANALOG_EN, HIGH);
  digitalWrite(Main_OE, HIGH);
  digitalWrite(Satellite_OE, HIGH);
  Serial.println("Done");




  //Config complete. Print menu.
  Serial.println("Setup complete");
  ldOdometer.home();
  ldOdometer.print(millis());

  Serial.println("Input Format is: '<X YYYYYYYY YYYYYYYY YYYYYYYY>'");
  Serial.println("Valid Chip Selects are: 3 4 6 9 10 12 24 25 26 27");
  Serial.println("Write to BI pin (5) to set output PWM width");
  Serial.println("Ready");

}

void loop() {
  // put your main code here, to run repeatedly:


  recvWithStartEndMarkers();

  if (newData == true) {
    printSerialData();
    parseSerialData();

    if (CSPin == BLANK_CONTROL) {
      analogWrite(BLANK_CONTROL, dataOut[0]);
      Serial.print("Brightness PWM to: "); Serial.println(dataOut[0]);
    }
    else if (CSPin == CS_DDC) {
      Serial.print("Discrete Input State: ");

      SPI2.beginTransaction(scInputs);
      digitalWrite(CS_DDC, LOW);
      digitalWrite(SPI2_LH, LOW);
      delayMicroseconds(5);
      digitalWrite(SPI2_LH, HIGH);
      stateDiscrete[0] = SPI2.transfer(0);
      stateDiscrete[1] = SPI2.transfer(0);
      stateDiscrete[2] = SPI2.transfer(0);
      digitalWrite(CS_DDC, HIGH);
      SPI2.endTransaction();

      printBinary(stateDiscrete[0]); Serial.print(" ");
      printBinary(stateDiscrete[1]); Serial.print(" ");
      printBinary(stateDiscrete[2]); Serial.println(" Complete");
    }
    else if (CSPin == CS_ADC) {
      adcTempPower = myADC.analogRead(0);
      adcVolts = myADC.analogRead(1);
      adcIllum = myADC.analogRead(2);
      adcPressureManifold = myADC.analogRead(3);
      adcFuelMain = myADC.analogRead(4);
      adcFuelSub = myADC.analogRead(5);
      adcPressureOil = myADC.analogRead(6);
      adcTempWater = myADC.analogRead(7);
      adcTempInt = analogRead(BOARD_TEMP);

      Serial.print("Ch0: "); Serial.println(adcTempPower);
      Serial.print("Ch1: "); Serial.println(adcVolts);
      Serial.print("Ch2: "); Serial.println(adcIllum);
      Serial.print("Ch3: "); Serial.println(adcPressureManifold);
      Serial.print("Ch4: "); Serial.println(adcFuelMain);
      Serial.print("Ch5: "); Serial.println(adcFuelSub);
      Serial.print("Ch6: "); Serial.println(adcPressureOil);
      Serial.print("Ch7: "); Serial.println(adcTempWater);
      Serial.print("Ch8: "); Serial.println(adcTempInt);
    }
    else if (CSPin == CS_BTN) {
      Serial.print("Button State: ");
      SPI1.beginTransaction(scInputs);
      digitalWrite(CS_BTN, LOW);
      digitalWrite(SPI1_LH, LOW);
      delayMicroseconds(5);
      digitalWrite(SPI1_LH, HIGH);
      stateButtons = SPI1.transfer(0);
      digitalWrite(CS_BTN, HIGH);
      SPI1.endTransaction();
      printBinary(stateButtons); Serial.println(" Complete");

    }

    else if (CSPin == 50) {
      setTachometer(dataOut[0]*100);
      
    }

    else if (CSPin == 51) {
      setSpeedometer(dataOut[0]);
    }

    else if (CSPin == 52) {
      setFuel(dataOut[0]);
    }

    else if (CSPin == 53) {
      setBar(dataOut[0], VOLTS_MIN, VOLTS_MAX, CS_DISP_VOLT);
    }
    else if (CSPin == 54) {
      setBar(dataOut[0], TEMP_MIN, TEMP_MAX, CS_DISP_TEMP);
    }
    else if (CSPin == 55) {
      setBar(dataOut[0], OIL_MIN, OIL_MAX, CS_DISP_OIL);
    }
    else if (CSPin == 99) {
      for (int i = 500; i < 7000; i = i + 100) {
        setTachometer(i);
        delay(100);
      }
      for (int j = 0; j < 299; j = j + 1) {
        setSpeedometer(j);
        delay(100);
      }
    }
    else {
      displayWrite(CSPin, 3, dataOut);

    }

    newData = false;
  }



}

void inputScan() {
  //poll input shift registers and adc


}

void recvWithStartEndMarkers() {
  static boolean recvInProgress = false;
  static byte ndx = 0;
  char startMarker = '<';
  char endMarker = '>';
  char rc;

  // if (Serial.available() > 0) {
  while (Serial.available() > 0 && newData == false) {
    rc = Serial.read();
    Serial.write(rc);
    if (recvInProgress == true) {
      if (rc != endMarker) {
        receivedChars[ndx] = rc;
        ndx++;
        if (ndx >= numChars) {
          ndx = numChars - 1;
        }
      }
      else {
        receivedChars[ndx] = '\0'; // terminate the string
        recvInProgress = false;
        ndx = 0;
        newData = true;
      }
    }

    else if (rc == startMarker) {
      recvInProgress = true;
    }
  }
}

void parseSerialData() {
  char * pEnd;
  //Format info:
  //<X YYYYYY YYYYYY YY>
  //Where X is the arduino digital pin controlling the chip selected, and YYYY is the data to be shifted out
  CSPin = strtol(receivedChars, &pEnd, 10);

  dataOut[0] = strtol(pEnd, &pEnd, 2);
  dataOut[1] = strtol(pEnd, &pEnd, 2);
  dataOut[2] = strtol(pEnd, NULL, 2);
}

//function to transfer data to FIP drivers
void displayWrite(int CSPin, int numBytes, byte data[5]) {

  Serial.print("ShiftOut to pin: "); Serial.print(CSPin); Serial.print(" Data: ");

  digitalWrite(CSPin, LOW);

  SPI1.beginTransaction(scDisplay);
  SPI2.beginTransaction(scDisplay);

  for (int i = 0; i < numBytes; i++) {
    printBinary(data[i]); Serial.print(" ");
    SPI1.transfer(data[i]); SPI2.transfer(data[i]);
  }
  Serial.println(" Latching");
  digitalWrite(SPI1_LH, LOW);
  digitalWrite(SPI2_LH, LOW);
  delayMicroseconds(5);
  digitalWrite(SPI1_LH, HIGH);
  digitalWrite(SPI2_LH, HIGH);
  digitalWrite(CSPin, HIGH);
  SPI1.endTransaction();
  SPI2.endTransaction();

}

void printBinary(byte inByte) {
  for (int b = 7; b >= 0; b--) {
    Serial.print(bitRead(inByte, b));
  }
}
void printSerialData() {
  Serial.print("In: ");
  Serial.println(receivedChars);
}

void setTachometer(int valueTach) {
  Serial.print("Setting Tach to: "); Serial.println(valueTach);
  byte tachNumber[3];
  tachNumber[0] = 00000000;
  tachNumber[1] = 00000000;
  tachNumber[2] = 00000000;
  //byte tachGraph [5];

  tachNumber[0] = Chars7Seg[(valueTach / 100)% 10];
  Serial.println((valueTach / 100)%10);
  tachNumber[1] = Chars7Seg[(valueTach /1000) % 10];
  Serial.println((valueTach/1000)%10);
  shiftRight(tachNumber, 3, 4);

  displayWrite(CS_TACH, 3, tachNumber);

}

void setSpeedometer(int valueSpeed) {
  
  byte speedNumber[3];
  speedNumber[0] = 00000000;
  speedNumber[1] = 00000000;
  speedNumber[2] = 00000000;
  //byte speedGraph [3];
  Serial.println(valueSpeed);
  speedNumber[0] = Chars7Seg[valueSpeed % 10];

  bitWrite(speedNumber[1], 7, 1);
  speedNumber[1] = Chars7Seg[(valueSpeed/10) % 10];

  shiftRight(speedNumber, 3, 4);
  if ((valueSpeed < 200) & (valueSpeed > 100)) {
    bitWrite(speedNumber[2], 3, 0);
    bitWrite(speedNumber[2], 2, 1);
  }
  else if (valueSpeed > 100) {
    bitWrite(speedNumber[2], 3, 1);
    bitWrite(speedNumber[2], 2, 0);
  }
  bitWrite(speedNumber[2], 0, 1);

  displayWrite(CS_SPEED, 3, speedNumber);
}

//accepts the numeric value for the parameter, and then places the gauge 
//cursor in the right spot
void setBar(int value, int rangeMin, int rangeMax, int target) {
  Serial.print("Setting to "); Serial.println(value);
  byte dataBar[3];
  dataBar[0] = 0b00000000;
  dataBar[1] = 0b00000000;
  dataBar[2] = 0b00001000;

  int level = constrain(map(value, 0, 255, rangeMin, rangeMax), rangeMin, rangeMax);
  bitWrite(dataBar[(level/8)+1], level%8, 1);

  displayWrite(target, 3, dataBar);
  
}

//accepts 0-255 for fuel level, converts to bar graph and numeric readout
void setFuel(uint8_t levelFuel) {
  int quantityFuel = ((long)levelFuel*FUEL_MAX) / 255;
  levelFuel = constrain(map(levelFuel, 0, 255, FUEL_MIN, FUEL_MAX), FUEL_MIN, FUEL_MAX);

  
  byte dataBar[3];
  dataBar[0] = 0b00000000;
  dataBar[1] = 0b00000000;
  dataBar[2] = 0b00001000;

  for (int i = 0; i < levelFuel; i++) {
    bitWrite(dataBar[(levelFuel/8)+1], levelFuel%8, 1);
  }
  
  
  byte dataNum[3];
  dataNum[0] = 0b00000000;
  dataNum[1] = Chars7Seg[quantityFuel%10];
  if (quantityFuel > 10) {
    dataNum[2] = 0b10000000;
  }
  else{
    dataNum[2] = 0b00000000;
  }

    displayWrite(CS_DISP_FUEL, 3, dataBar);
    displayWrite(CS_DISP_FUEL2, 3, dataNum);
  
}

void shiftRight(byte a[], int arraySize, int numShift) {
  int lastBit;
  int prevLastBit;
  for (int i = 1; i <= numShift; i++) {

    for (int j = 0; j <= arraySize-1; j++) {
      lastBit = bitRead(a[j], 0);
      a[j] >>= 1;

      if (j > 0) {
        bitWrite(a[j], 7, prevLastBit);
      }
      prevLastBit = lastBit;
    }
  }
}

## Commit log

2022-04-08 Add & commit board designs
    [DD_Compute_1.kicad_pcb, DD_Compute_1.sch, DD_Odometer_Module_1.kicad_pcb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]
2022-09-29 Catchup Commit
    [DD_Compute_1.sch]
2025-03-21 Catchup commit.
    [DD_Compute_2.kicad_pcb, DD_Compute_2.kicad_sch, DD_Odometer_Module_1.kicad_pcb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]
2025-03-21 Update README.md to reflect current state.
2025-04-20 warning module update; ws2812->ws2813 (backup data in)
    [DD_Compute_2.kicad_pcb, DD_Warning_Module_1.kicad_pcb, DD_Warning_Module_1.kicad_sch]
